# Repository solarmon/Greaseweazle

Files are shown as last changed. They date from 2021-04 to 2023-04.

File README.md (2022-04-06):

# Greaseweazle Projects
Greaseweazle Projects

Various PCB projects based on **keirf**'s Greaseweazle project for reading and writing floppy disks:

https://github.com/keirf/Greaseweazle

Special thanks to **Stefano Cappelli** of https://www.picoelements.com/ for making the time and effort to beta testing these boards. 

# Greaseweazle F1 Plus

## Features

These are the features of the GW F1 Plus boards.

**Standard Features:**
| | F1 Plus Mini Rev 1.1 | F1 Plus  Rev 1.1 | F1 Plus Gotek	 Rev 1.1 | F1 Plus 3.5" Rev 1.1 |
|---|---|---|---|---|
|Jumperless Update|Yes|Yes|Yes|Yes|
|Multiple Drives|Yes|Yes|Yes|Yes|
|Write-Protect Jumper| - |Yes|Yes|Yes|
|Buffered Outputs| - |Yes|Yes|Yes|
|High-Speed USB| - | - | - | - |			
|12v Power| - |Yes|Yes|Yes|
|Flippy Drive| - |Yes|Yes|Yes|
|Disk Change Detect|Yes|Yes|Yes|Yes|
|User Outputs|3|3|3|3|

Note: **Disk Change Detect** allows WinUAE integration - see https://amiga.robsmithdev.co.uk/winuae

The features of the official Greaseweazle models can be seen at:

https://github.com/keirf/Greaseweazle/wiki/Greaseweazle-Models

**Other Features:**
| | F1 Plus Mini Rev 1.1 | F1 Plus  Rev 1.1 | F1 Plus Gotek	 Rev 1.1 | F1 Plus 3.5" Rev 1.1 |
|---|---|---|---|---|
|Gotek Case Form Factor| - | -  |Yes|		-		|
|3.5" Floppy Drive Form Factor| - | - |		-		|			Yes|
|STM32 Blue Pill MCU|Yes|Yes|Yes|Yes|
|**Arduino Nano Track Display:**| - | - |		Yes|				Yes|
|	- LEDC68 Display| - | - |			Yes|				Yes|
|	- 0.91" OLED Display| - | - |		(Yes)|			Yes|
|	- 0.96" OLED Display| - | - |		(Yes)|			Yes|
|	- SD Card Reader| - | - |			Yes|				Yes|
|USB ESD Protection| - | (Yes) |				Yes|				Yes|
|12V Reverse Polarity Protection| - | Yes |	Yes|				Yes|
|Poly Fuse| - |Yes|						Yes|				Yes|
|**LED Status:**|Yes|Yes|						Yes|				Yes|
|	- Activity|Yes|Yes|					Yes|				Yes|
|	- 3.3V|Yes|Yes|						Yes|				Yes|
|	- 5V|Yes|Yes|							Yes|				Yes|
|	- 12V| - |Yes |							Yes|				Yes|
| - Type: SMT|Yes|Yes| - | Yes|
| - Type: THT|Yes|Yes| Yes | Yes|
|**Power Jumpers:**|Yes|Yes|						Yes|				Yes|
|	- 12V|-|Yes|Yes|Yes|
|	- 5V|Yes|Yes|Yes|Yes|
|Write Enable Jumper| - |Yes|				Yes|				Yes|
|Input pullups|Yes|Yes|					Yes|				Yes|
|Reset Button|Yes|Yes|					Yes|				Yes|
|Serial Programming Header|Yes|Yes|		Yes|				Yes|
|SWD Programming Header|-|Yes|			Yes|				Yes|
|Disk Change Jumper|Yes|Yes|Yes|Yes|

**Note:** The **Disk Change Jumper** allows you to use an Amiga drive with WinUAE.

## Greaseweazle F1 Plus Mini Rev 1.1

**Design Files:** https://github.com/solarmon/Greaseweazle/tree/main/Greaseweazle%20F1%20Plus%20Mini%20Rev%201.1

This is the most basic F1 Plus model and has the smallest footprint.

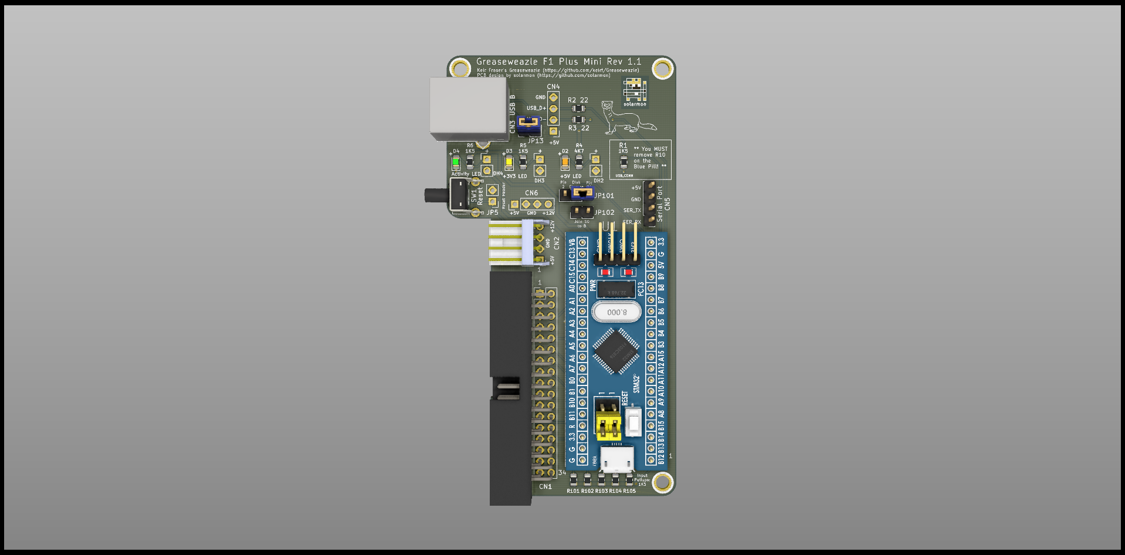
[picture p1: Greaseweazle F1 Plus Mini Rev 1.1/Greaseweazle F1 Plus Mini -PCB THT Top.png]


## Greaseweazle F1 Plus Rev 1.1

**Design Files:** https://github.com/solarmon/Greaseweazle/tree/main/Greaseweazle%20F1%20Plus%20Rev%201.1

This is the standard F1 Plus model, has a standard footprint but no Track Display features. 

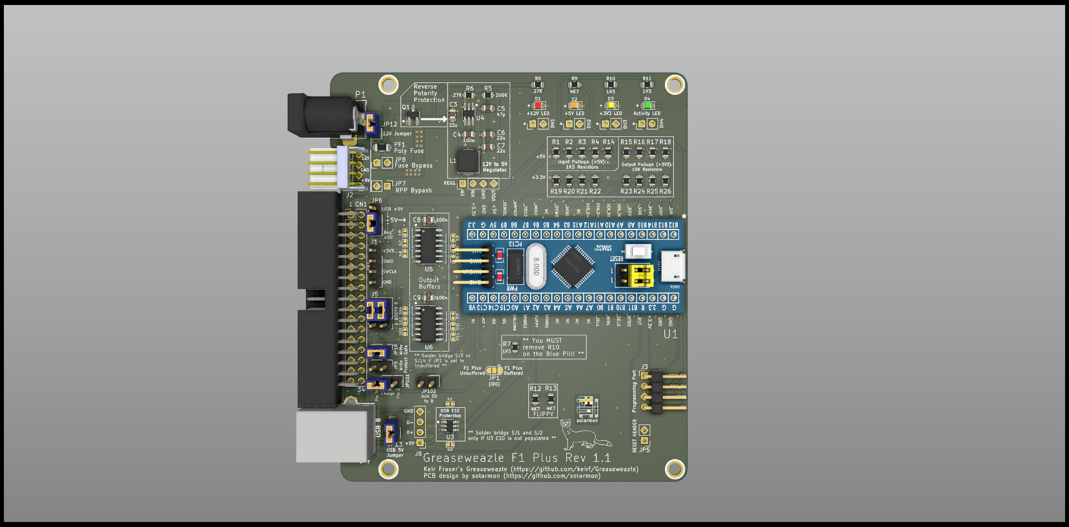
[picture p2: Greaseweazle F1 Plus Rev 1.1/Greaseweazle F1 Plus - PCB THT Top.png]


## Greaseweazle F1 Plus Gotek

**Design Files:** https://github.com/solarmon/Greaseweazle/tree/main/Greaseweazle%20F1%20Plus%20Gotek%20Rev%201.1

This Greaseweazle board has been designed to re-purpose and fit into an original Gotek case; and to make use of its LEDC68 display as a track display.

It has been designed to sit on top of the floppy drive that is connected to it.

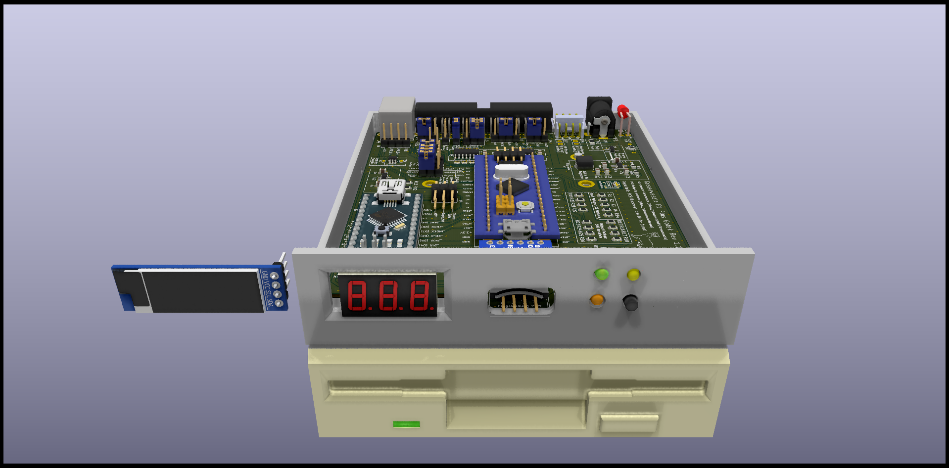
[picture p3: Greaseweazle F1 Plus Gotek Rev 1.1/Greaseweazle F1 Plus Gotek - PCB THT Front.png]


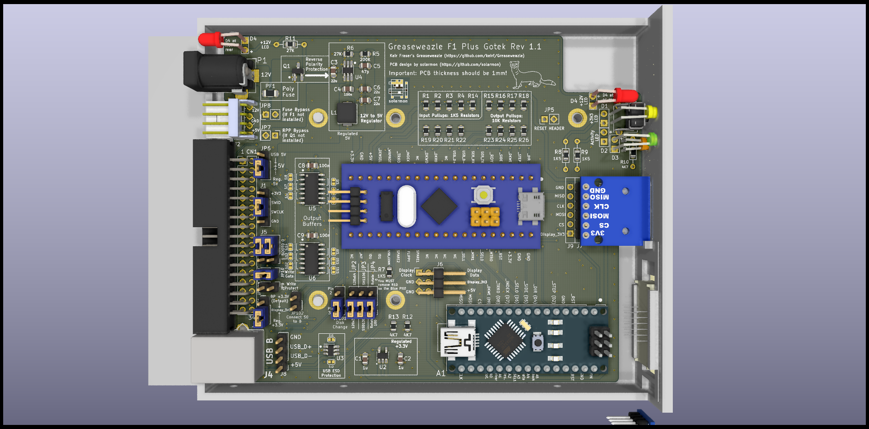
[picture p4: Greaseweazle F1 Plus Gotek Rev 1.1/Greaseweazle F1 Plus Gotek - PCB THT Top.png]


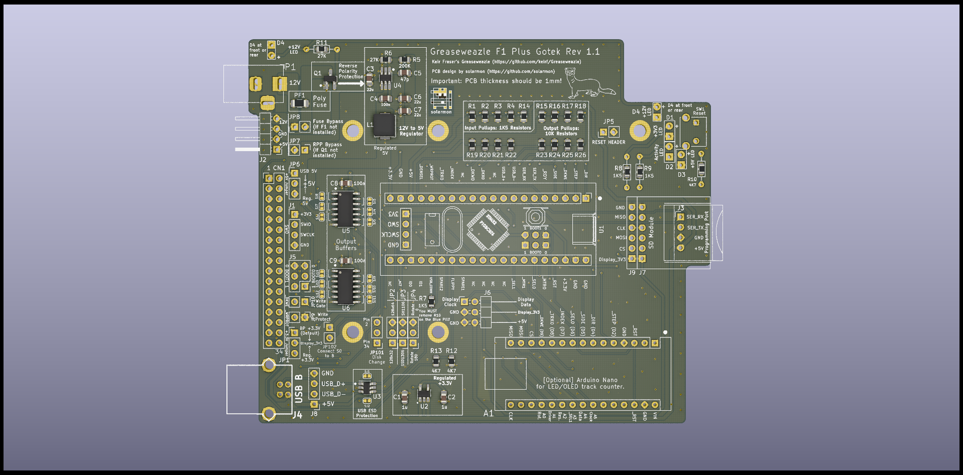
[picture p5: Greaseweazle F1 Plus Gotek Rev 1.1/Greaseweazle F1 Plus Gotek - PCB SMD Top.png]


## Greaseweazle F1 Plus 3.5"

**Design Files:** https://github.com/solarmon/Greaseweazle/tree/main/Greaseweazle%20F1%20Plus%203.5%20Rev%201.1

This Greaseweazle board has been designed to have a 3.5" floppy drive mounted directly on top of it, using the floppy drive standard mounting holes.

The track display feature can support the LEDC68 Gotek LED display, or a 128x32 0.91" OLED display, or a 128x64 0.96" OLED display.

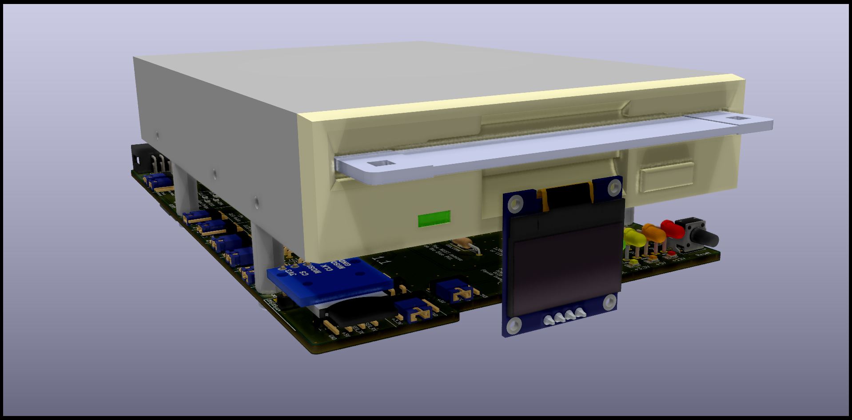
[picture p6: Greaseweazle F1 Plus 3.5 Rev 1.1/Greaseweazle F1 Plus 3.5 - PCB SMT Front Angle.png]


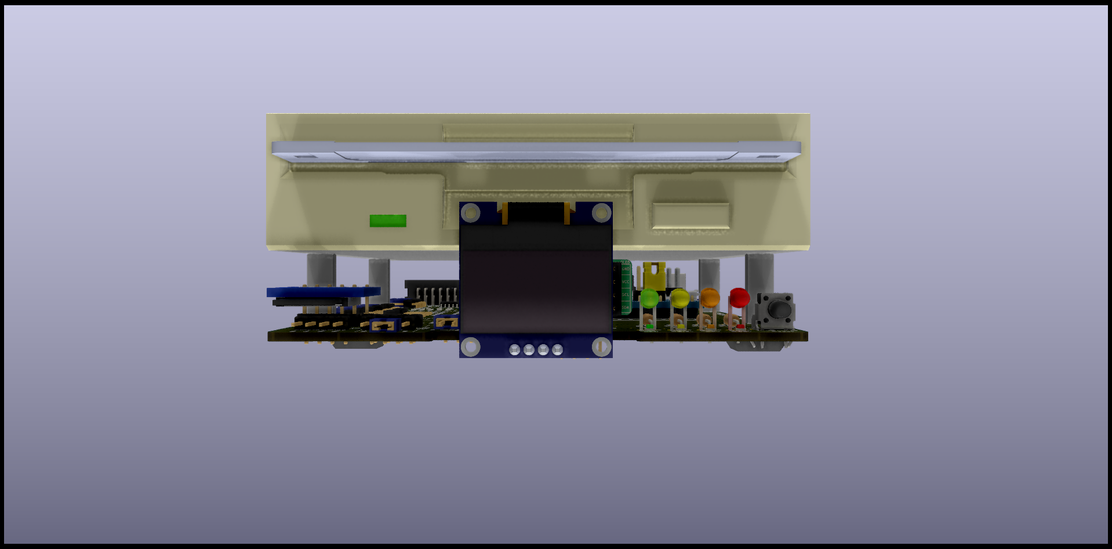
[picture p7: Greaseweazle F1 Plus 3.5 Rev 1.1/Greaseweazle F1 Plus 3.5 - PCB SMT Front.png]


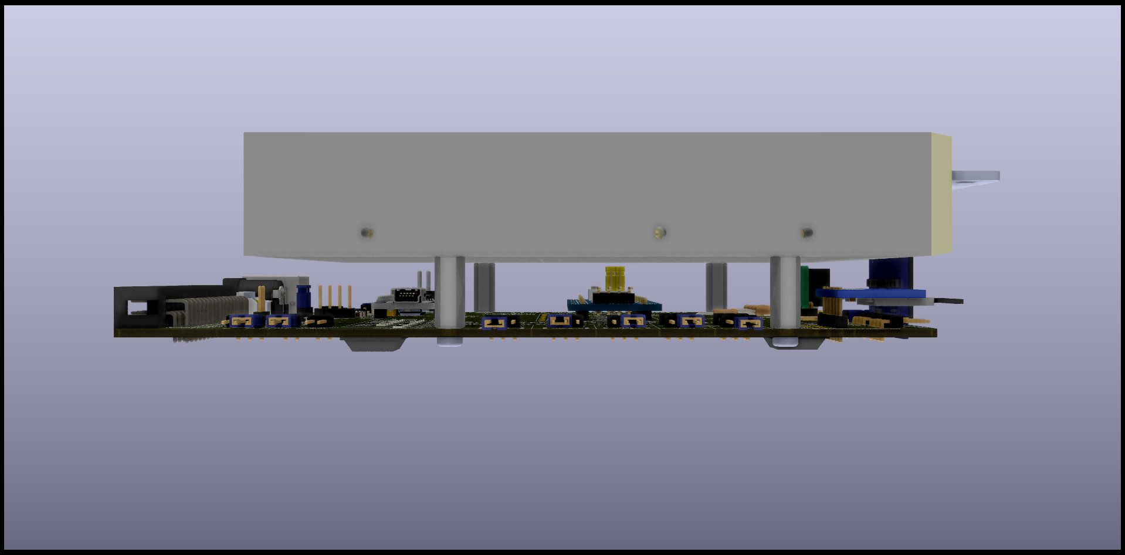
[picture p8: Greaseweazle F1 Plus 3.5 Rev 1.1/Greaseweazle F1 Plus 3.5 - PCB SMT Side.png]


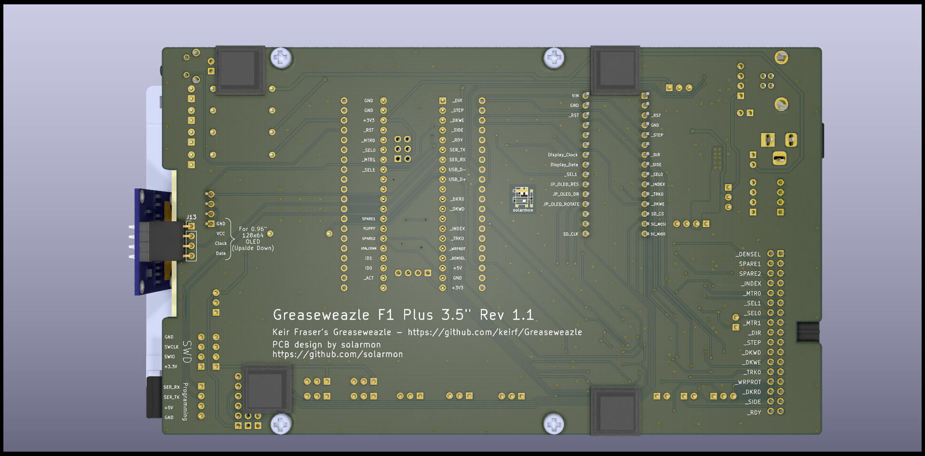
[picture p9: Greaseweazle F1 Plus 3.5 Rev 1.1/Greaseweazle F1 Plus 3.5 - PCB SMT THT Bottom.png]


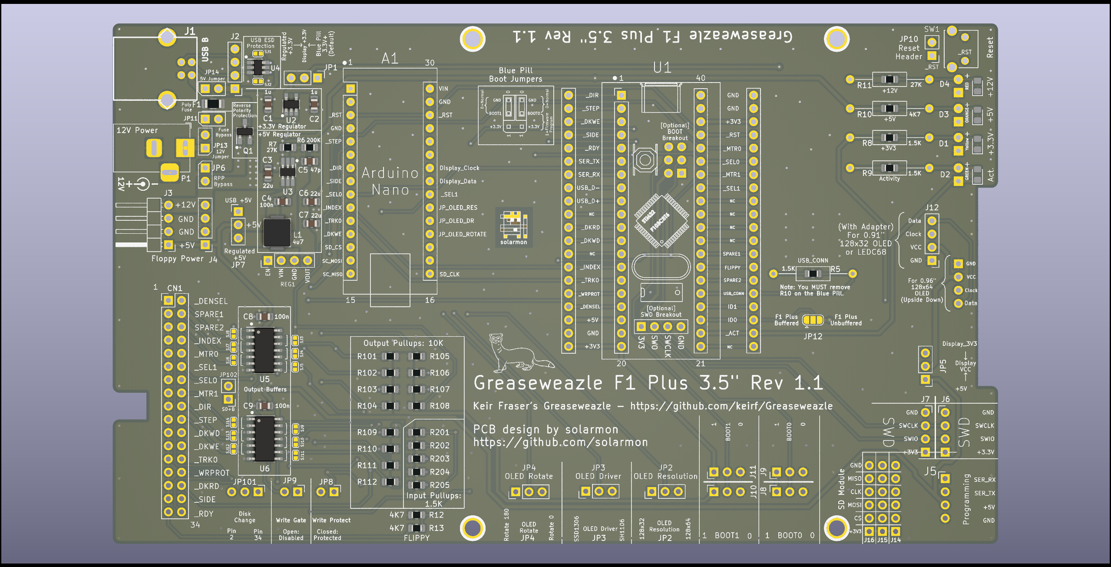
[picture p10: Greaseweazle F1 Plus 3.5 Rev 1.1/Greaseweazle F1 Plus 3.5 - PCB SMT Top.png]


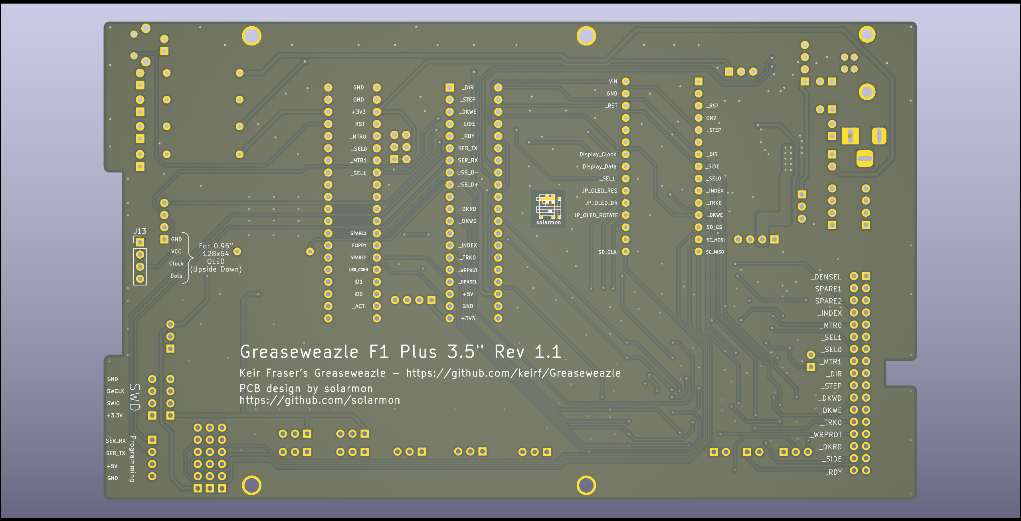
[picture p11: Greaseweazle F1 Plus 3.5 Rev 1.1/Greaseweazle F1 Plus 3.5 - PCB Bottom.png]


## Track Display

The GW F1 Plus Gotek/3.5" Track Display is provided by an Arduino Nano. The Arduino sketch for this can be found at:

https://github.com/solarmon/Greaseweazle/tree/main/Arduino_Nano_GW_F1_Plus_Floppy_Drive_Track_Display_LED_and_OLED

The LEDC68 and OLED display adapter board, used in the GW F1 3.5" and GW F1 Plus 3.5" boards, can be found at:

https://github.com/solarmon/Greaseweazle/tree/main/LEDC68%20and%200.9%20Inch%20OLED%20Adapter

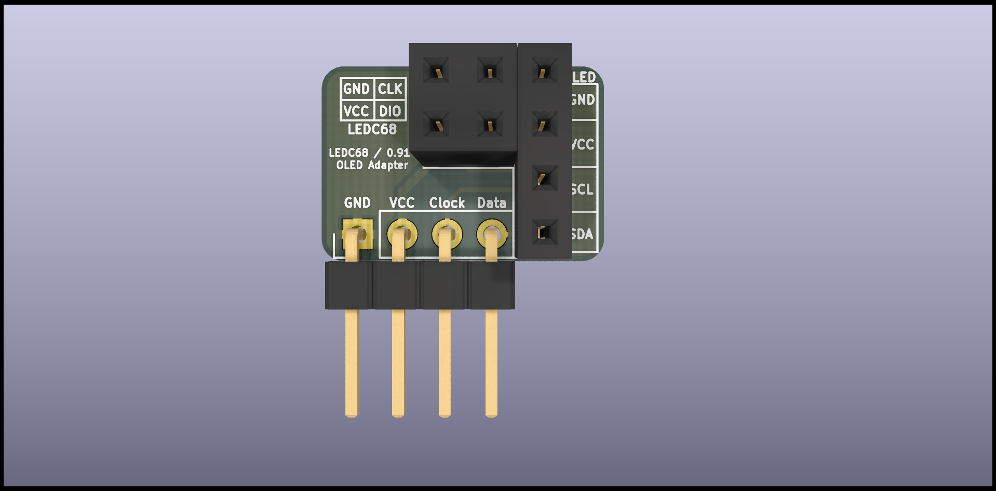
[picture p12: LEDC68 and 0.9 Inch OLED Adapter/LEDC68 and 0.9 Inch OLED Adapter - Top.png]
Top


# Older Revisions

Design files for older revisions of the GW F1 boards can be found at:

## GW F1 Plus Mini

* Rev 1: https://github.com/solarmon/Greaseweazle/tree/main/Greaseweazle%20F1%20Plus%20Mini
 
## GW F1 Plus

* Rev 1: https://github.com/solarmon/Greaseweazle/tree/main/Greaseweazle%20F1%20Plus

## GW F1 Plus Gotek

* Rev 1: https://github.com/solarmon/Greaseweazle/tree/main/Greaseweazle%20F1%20Plus%20Gotek

## GW F1 Plus 3.5"

* Rev 1: https://github.com/solarmon/Greaseweazle/tree/main/Greaseweazle%20F1%20Plus%203.5

## GW F1 Gotek

* Rev 1 (USB-B): https://github.com/solarmon/Greaseweazle/tree/main/Greaseweazle%20F1%20in%20a%20Gotek%20Case%20(%2B%20USB%20B)
* Rev 1 (USB-A): https://github.com/solarmon/Greaseweazle/tree/main/Greaseweazle%20F1%20in%20a%20Gotek%20Case%20(USB-A)
* Rev 2: https://github.com/solarmon/Greaseweazle/tree/main/Greaseweazle%20F1%20Gotek%20Rev%202
* Rev 2B: https://github.com/solarmon/Greaseweazle/tree/main/Greaseweazle%20F1%20Gotek%20Rev%202B

## GW F1 3.5"

* Rev 1: https://github.com/solarmon/Greaseweazle/tree/main/Greaseweazle%20F1%203.5%20Inch
* Rev 2: https://github.com/solarmon/Greaseweazle/tree/main/Greaseweazle%20F1%203.5%20Inch%20Rev%202
* Rev 2B: https://github.com/solarmon/Greaseweazle/tree/main/Greaseweazle%20F1%203.5%20Inch%20Rev%202B

## Track Display

These older revision GW F1 Plus Track Display is provided by an Arduino Nano. The Arduino sketch for this can be found at:

https://github.com/solarmon/Greaseweazle/tree/main/Arduino_Nano_GW_F1_Floppy_Drive_Track_Display_LED_and_OLED_v1

The LEDC68 and OLED display adapter board can be found at:

https://github.com/solarmon/Greaseweazle/tree/main/LEDC68%20and%200.9%20Inch%20OLED%20Adapter

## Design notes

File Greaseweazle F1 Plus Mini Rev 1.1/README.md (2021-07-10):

# Greaseweazle F1 Plus Mini

This is the most basic F1 Plus model and has the smallest footprint.

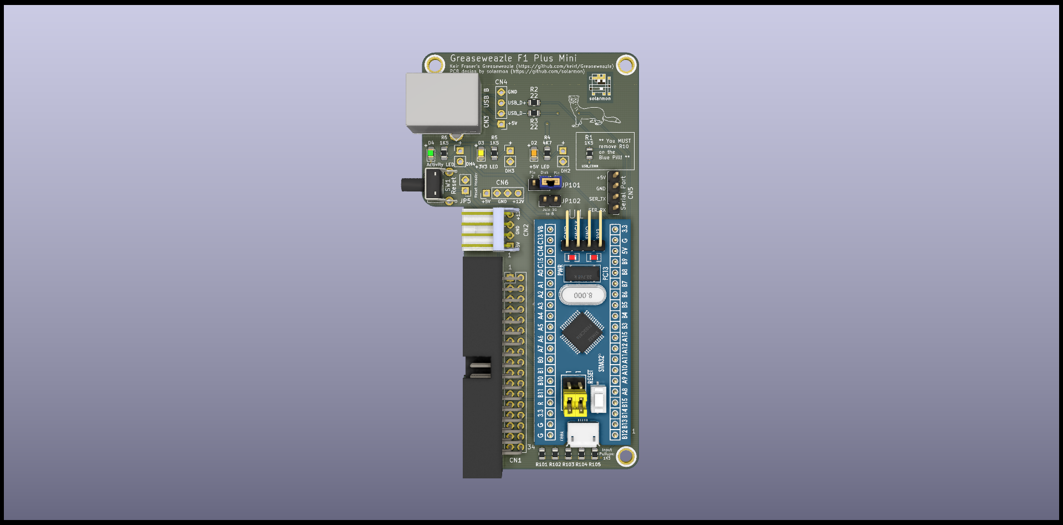
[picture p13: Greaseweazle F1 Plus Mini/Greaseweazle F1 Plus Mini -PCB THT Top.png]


## Jumpers

* **JP101** - Disk Change
  - **Pin 34** (Default) - For PC drives
  - **Pin 2** - For Amiga drives

* **JP102** - Join S0/B
  - If **JP101** set to **Pin 2** then set JP102 to join S0 with B

To use an **Amiga** floppy drive with WinUAE, jumper **JP101** to **Pin 2** and jumper **JP102**. An Amiga drive set to S0 will be usable in WinuAE as drive B.

## Headers

* **JP5** - Reset

* **CN4** - USB Header

* **CN5** - Serial Port

* **DH2** - +5V LED
* **DH3** - +3V3 LED
* **DH4** - ACT LED

## Connectors

* **CN1** - Floppy Data
* **CN2** - Floppy Power (Out)
* **CN3** - USB B
* **CN6** - Floppy Power (In)

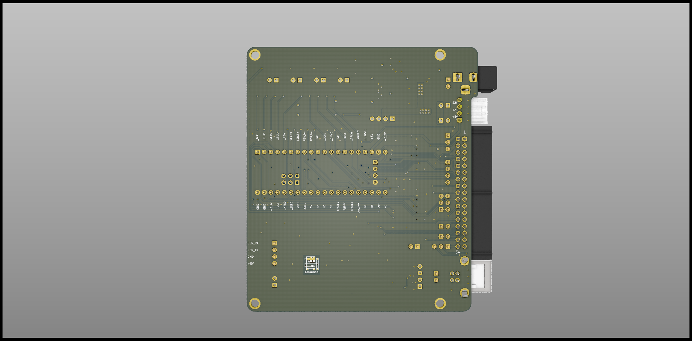
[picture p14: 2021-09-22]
Greaseweazle F1 Plus Rev 1.1/Greaseweazle F1 Plus - PCB THT Bottom.png

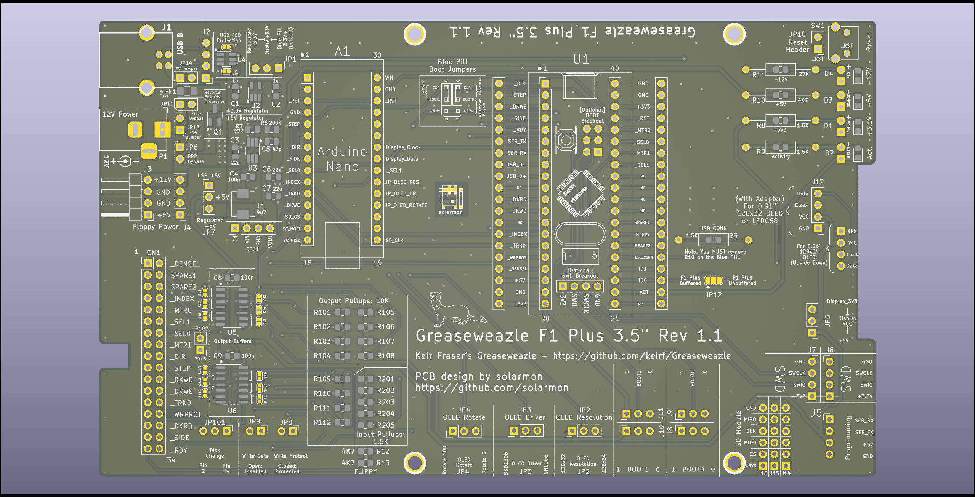
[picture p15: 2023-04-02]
Greaseweazle F1 Plus 3.5 Rev 1.1/Greaseweazle F1 Plus 3.5 - PCB Top.png

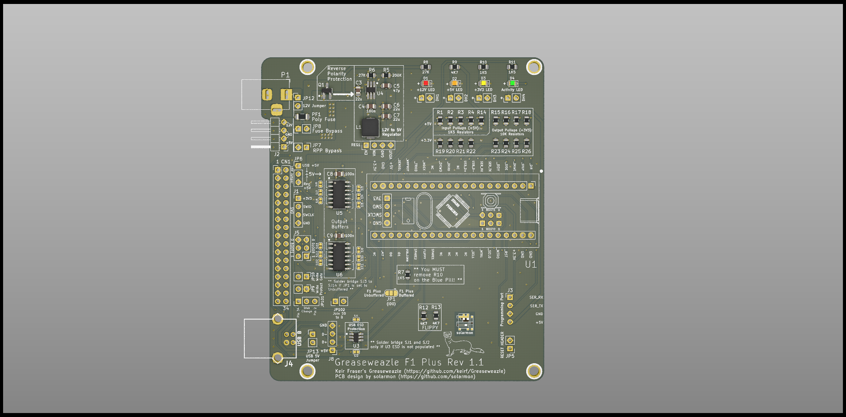
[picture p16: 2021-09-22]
Greaseweazle F1 Plus Rev 1.1/Greaseweazle F1 Plus - PCB SMT Top.png

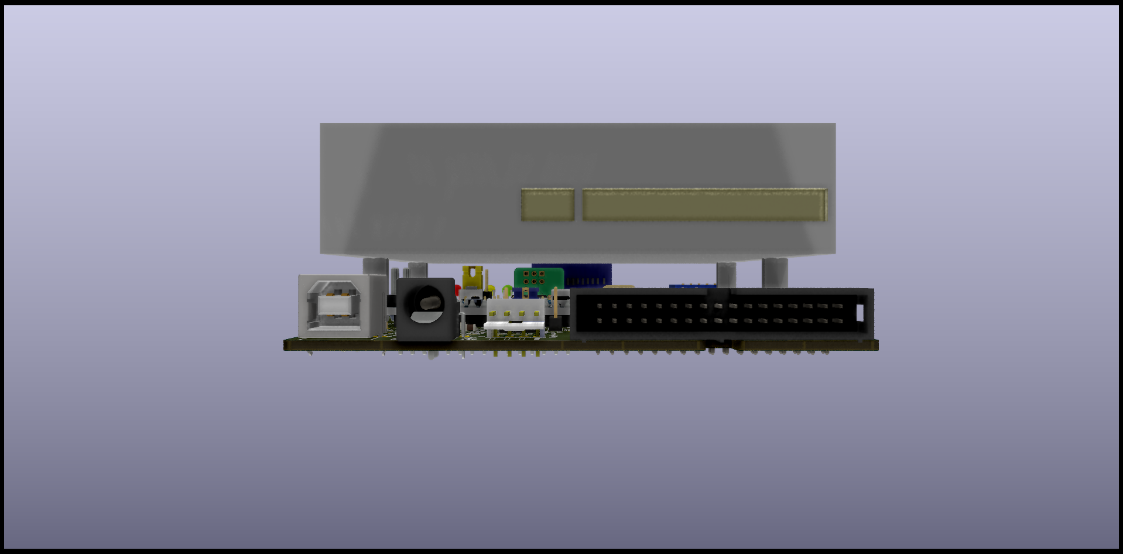
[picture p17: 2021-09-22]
Greaseweazle F1 Plus 3.5 Rev 1.1/Greaseweazle F1 Plus 3.5 - PCB SMT Rear.png

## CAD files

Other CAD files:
LEDC68 and 0.9 Inch OLED Adapter/DXF/LEDC68 and 0.9 Inch OLED Adapter-B_SilkS.dxf
LEDC68 and 0.9 Inch OLED Adapter/DXF/LEDC68 and 0.9 Inch OLED Adapter-F_SilkS.dxf

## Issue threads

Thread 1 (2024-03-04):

3D model of the FDD connector

Freiwind, 2024-03-04:
The first pin on the 3D model of the FDD connector does not match specified on the PCB.
It must be turned 180 degrees.

solarmon, 2024-03-04:
Hi,

For which Greaseweazle model?

Regards.

Freiwind, 2024-03-04:
At least for F1 Plus Gotek Rev 1.1 and F1 Plus Rev 1.1
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

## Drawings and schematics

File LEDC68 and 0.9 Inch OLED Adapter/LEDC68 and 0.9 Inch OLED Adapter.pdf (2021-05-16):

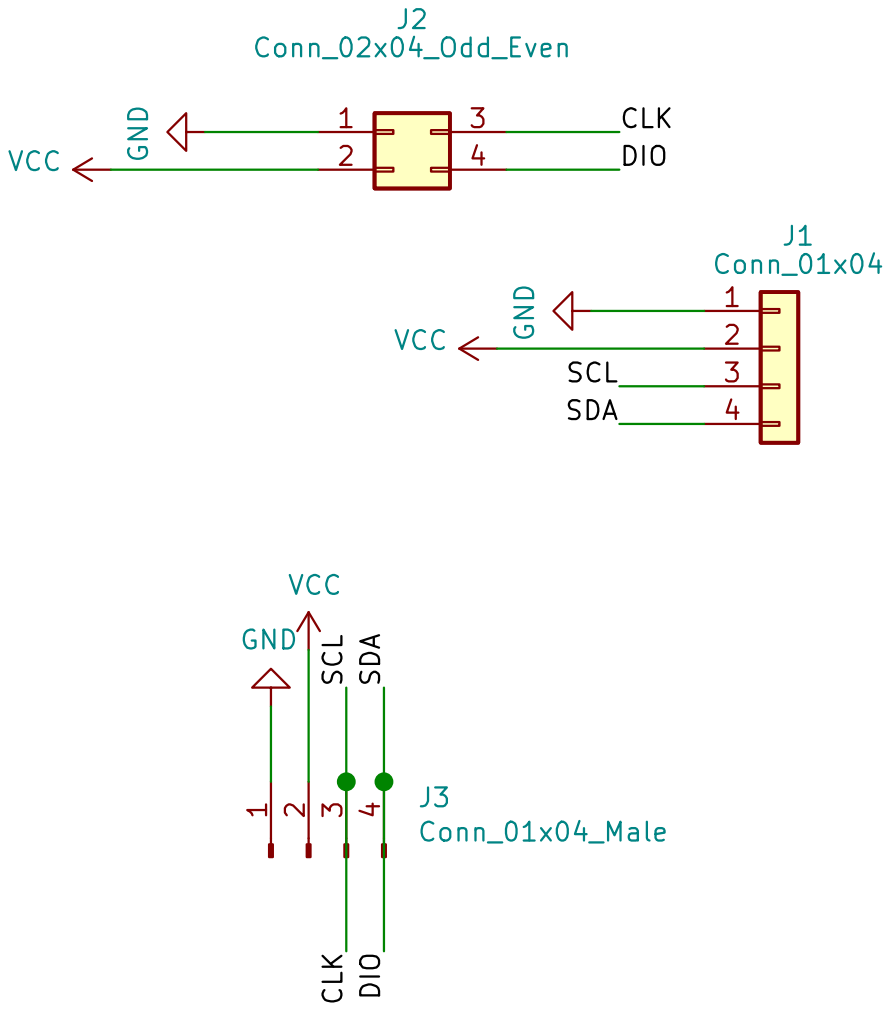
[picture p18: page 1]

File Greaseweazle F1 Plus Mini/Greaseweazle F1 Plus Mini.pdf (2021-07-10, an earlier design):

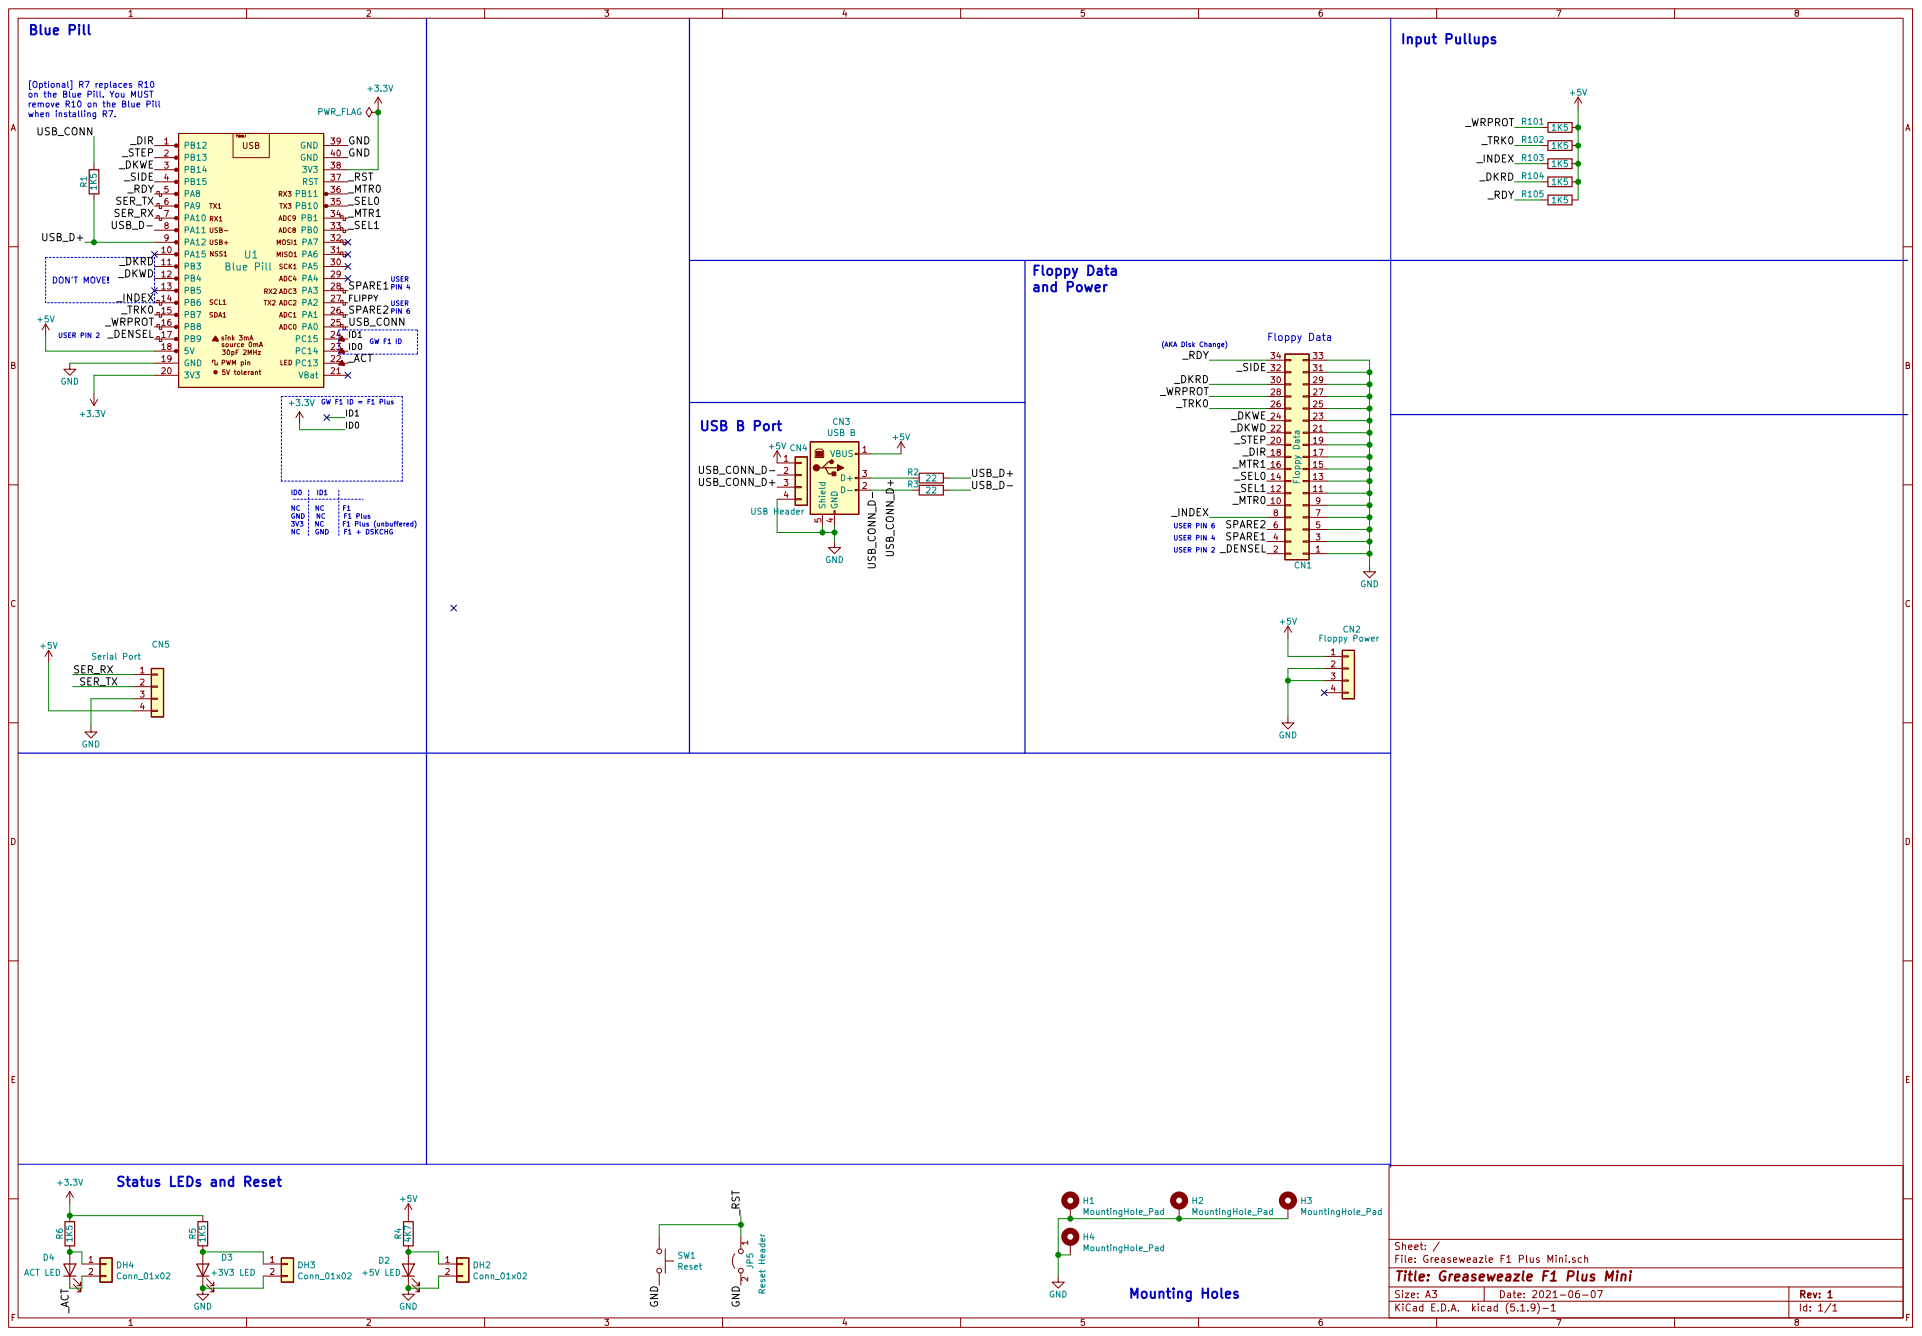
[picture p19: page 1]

[Optional] R7 replaces R10
on the Blue Pill. You MUST

5 CN3 USB B GND R6 1K5 D4 ACT LED

Status LEDs and Reset

Id: 1/1 Title: Greaseweazle F1 Plus Mini File: Greaseweazle F1 Plus Mini.sch Sheet: / R5 1K5

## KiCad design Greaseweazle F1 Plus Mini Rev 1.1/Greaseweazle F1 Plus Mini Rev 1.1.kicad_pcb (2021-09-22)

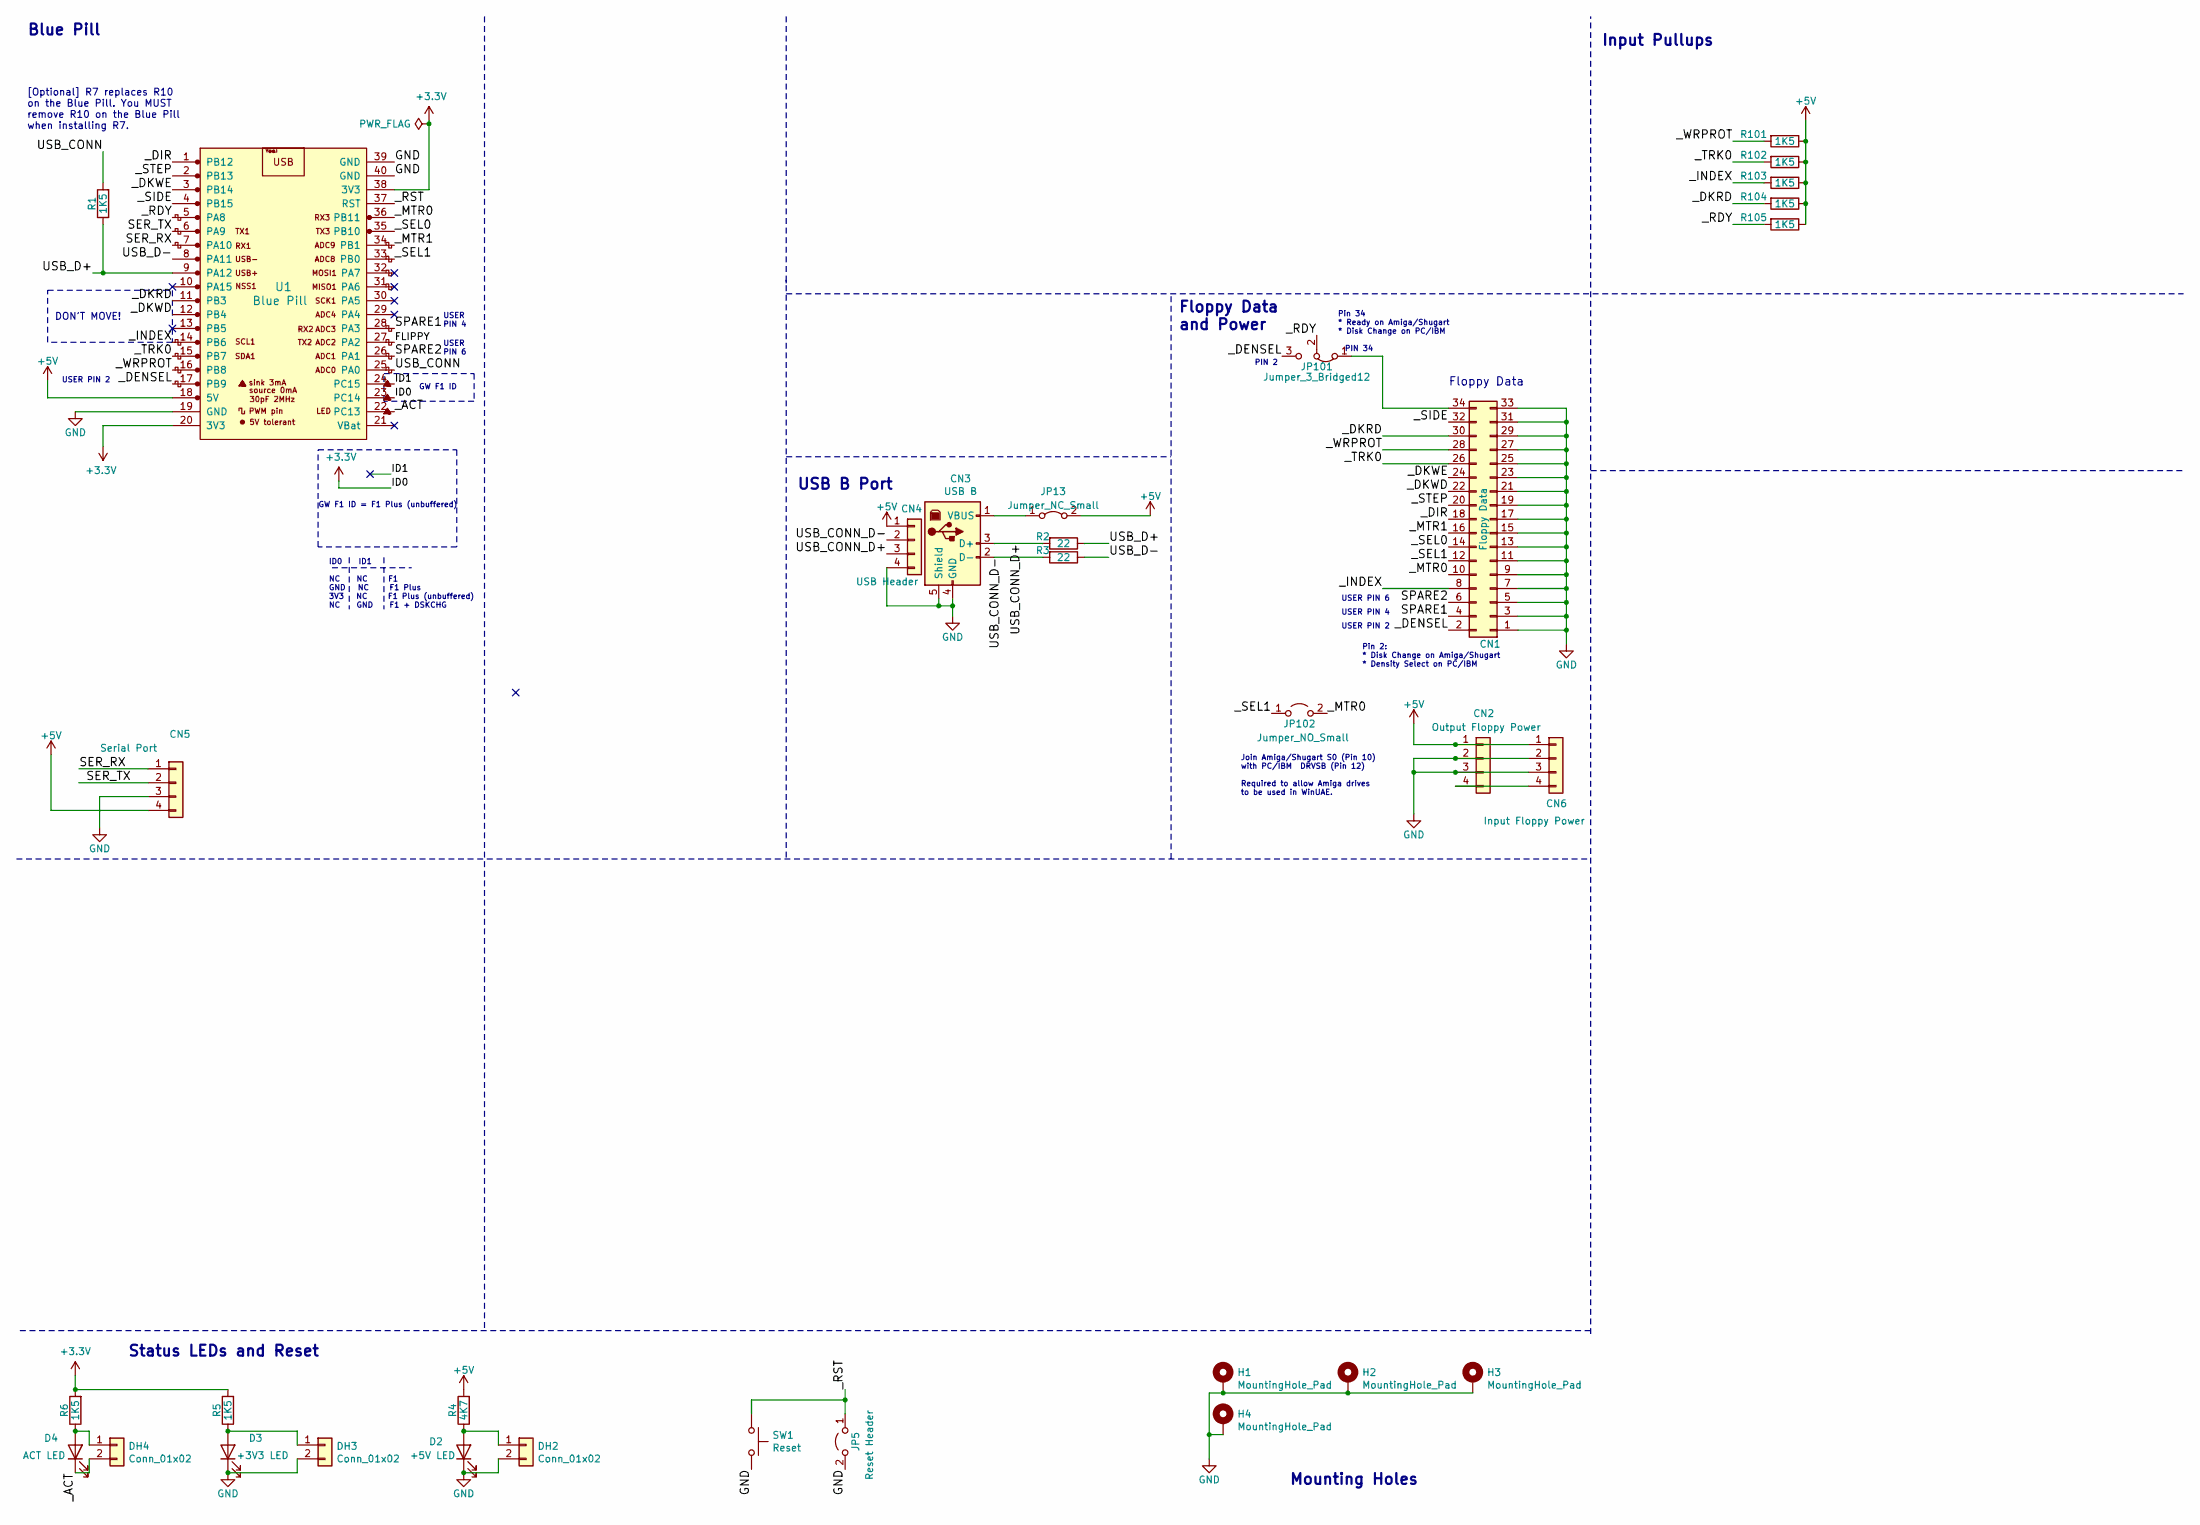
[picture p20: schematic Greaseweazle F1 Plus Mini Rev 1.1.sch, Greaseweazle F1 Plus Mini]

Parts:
CN1: Floppy Data; PinHeader_2x17_P2.54mm_Vertical
CN2: Output Floppy Power; PinHeader_1x04_P2.54mm_Horizontal
CN3: USB B; conn_usb_B; LCSC C498173
CN4: USB Header; PinHeader_1x04_P2.54mm_Vertical
CN5: Serial Port; PinHeader_1x04_P2.54mm_Vertical
CN6: Input Floppy Power; PinHeader_1x04_P2.54mm_Vertical
D2: +5V LED; LED_0805_2012Metric_Pad1.15x1.40mm_HandSolder
D3: +3V3 LED; LED_0805_2012Metric_Pad1.15x1.40mm_HandSolder
D4: ACT LED; LED_0805_2012Metric_Pad1.15x1.40mm_HandSolder
DH2, DH3, DH4: Conn_01x02; PinHeader_1x02_P2.54mm_Vertical
H1, H2, H3, H4: MountingHole_Pad; HOLE_3MM
JP5: Reset Header; PinHeader_1x02_P2.54mm_Vertical
JP13: Jumper_NC_Small; PinHeader_1x02_P2.54mm_Vertical
JP101: Jumper_3_Bridged12; PinHeader_1x03_P2.54mm_Vertical
JP102: Jumper_NO_Small; PinHeader_1x02_P2.54mm_Vertical
R1, R101, R102, R103, R104, R105: 1K5; R_0805_2012Metric
R2, R3: 22; R_0805_2012Metric
R4: 4K7; R_0805_2012Metric_Pad1.20x1.40mm_HandSolder
R5, R6: 1K5; R_0805_2012Metric_Pad1.20x1.40mm_HandSolder
SW1: Reset; SW_Tactile_SPST_Angled_PTS645Vx83-2LFS
U1: Blue Pill; YAAJ_BluePill_1

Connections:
+3V3: R5.2, R6.2, U1.20 (3V3), U1.23 (PC14), U1.38 (3V3)
+5V: CN2.1, CN4.1, CN5.4, CN6.1, JP13.2 (B), R4.2, R101.1, R102.1, R103.1, R104.1, R105.1, U1.18 (5V)
/FLIPPY: U1.27 (PA2)
/ID1: U1.24 (PC15)
/SER_RX: CN5.1, U1.7 (PA10)
/SER_TX: CN5.2, U1.6 (PA9)
/SPARE1: CN1.4, U1.28 (PA3)
/SPARE2: CN1.6, U1.26 (PA1)
/USB_CONN: R1.2, U1.25 (PA0)
/USB_CONN_D+: CN3.3 (D+), CN4.3, R2.2
/USB_CONN_D-: CN3.2 (D-), CN4.2, R3.2
/USB_D+: R1.1, R2.1, U1.9 (PA12)
/USB_D-: R3.1, U1.8 (PA11)
/_ACT: D4.1 (K), DH4.2, U1.22 (PC13)
/_DENSEL: CN1.2, JP101.3 (B), U1.17 (PB9)
/_DIR: CN1.18, U1.1 (PB12)
/_DKRD: CN1.30, R104.2, U1.11 (PB3)
/_DKWD: CN1.22, U1.12 (PB4)
/_DKWE: CN1.24, U1.3 (PB14)
/_INDEX: CN1.8, R103.2, U1.14 (PB6)
/_MTR0: CN1.10, JP102.2 (B), U1.36 (PB11)
/_MTR1: CN1.16, U1.34 (PB1)
/_RDY: JP101.2 (C), R105.2, U1.5 (PA8)
/_RST: JP5.1 (A), SW1.1, U1.37 (RST)
/_SEL0: CN1.14, U1.35 (PB10)
/_SEL1: CN1.12, JP102.1 (A), U1.33 (PB0)
/_SIDE: CN1.32, U1.4 (PB15)
/_STEP: CN1.20, U1.2 (PB13)
/_TRK0: CN1.26, R102.2, U1.15 (PB7)
/_WRPROT: CN1.28, R101.2, U1.16 (PB8)
GND: CN1.1, CN1.3, CN1.5, CN1.7, CN1.9, CN1.11, CN1.13, CN1.15, CN1.17, CN1.19, CN1.21, CN1.23, CN1.25, CN1.27, CN1.29, CN1.31, CN1.33, CN2.2, CN2.3, CN3.4 (GND), CN3.5 (Shield), CN4.4, CN5.3, CN6.2, CN6.3, D2.1 (K), D3.1 (K), DH2.2, DH3.2, H1.1, H2.1, H3.1, H4.1, JP5.2 (B), SW1.2, U1.19 (GND), U1.39 (GND), U1.40 (GND)
unnamed: CN1.34, JP101.1 (A)
unnamed: CN2.4, CN6.4
unnamed: CN3.1 (VBUS), JP13.1 (A)
unnamed: D2.2 (A), DH2.1, R4.1
unnamed: D3.2 (A), DH3.1, R5.1
unnamed: D4.2 (A), DH4.1, R6.1

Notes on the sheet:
Floppy Data
[Optional] R7 replaces R10 on the Blue Pill. You MUST remove R10 on the Blue Pill when installing R7.
USB B Port
Floppy Data and Power
Blue Pill
Status LEDs and Reset
Mounting Holes
GW F1 ID = F1 Plus (unbuffered)
GW F1 ID
DON'T MOVE!
Input Pullups
USER PIN 2
USER PIN 4
USER PIN 6
USER PIN 4
USER PIN 6
Pin 34 * Ready on Amiga/Shugart * Disk Change on PC/IBM
ID0 ID1 NC NC F1 GND NC F1 Plus 3V3 NC F1 Plus (unbuffered) NC GND F1 + DSKCHG
Pin 2: * Disk Change on Amiga/Shugart * Density Select on PC/IBM
Join Amiga/Shugart S0 (Pin 10) with PC/IBM DRVSB (Pin 12) Required to allow Amiga drives to be used in WinUAE.
PIN 2
PIN 34

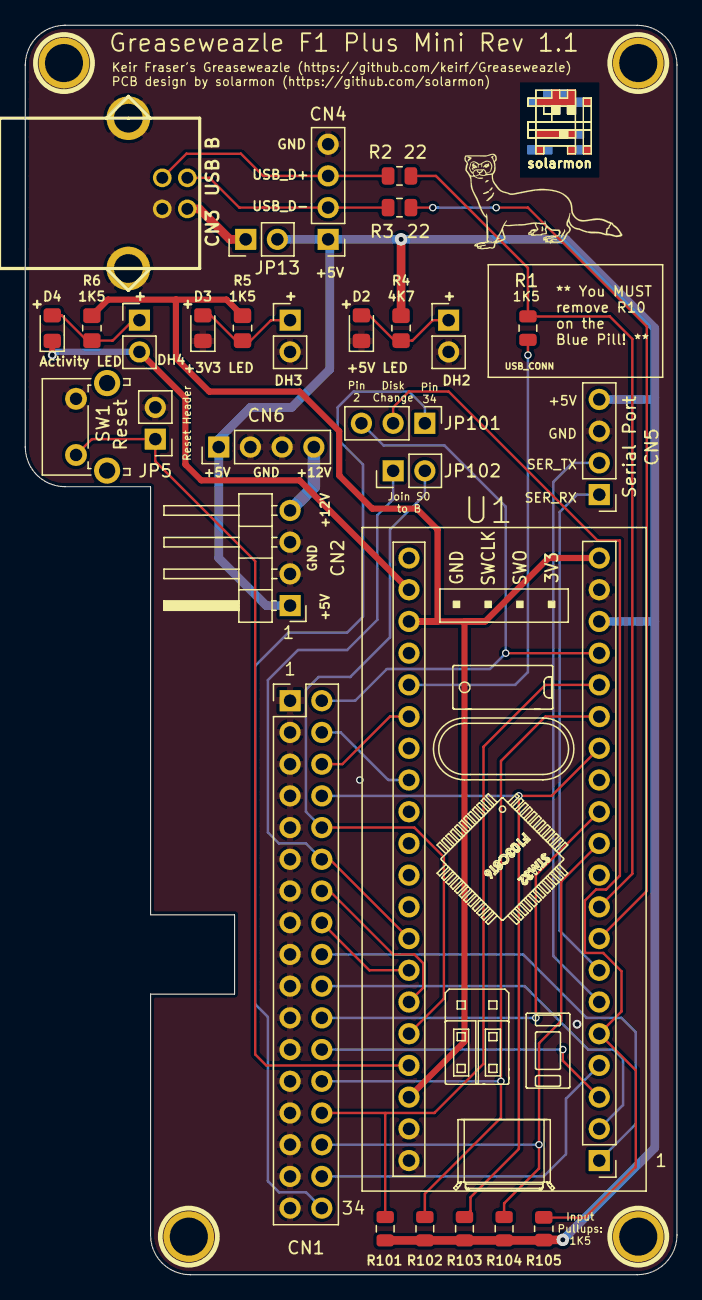
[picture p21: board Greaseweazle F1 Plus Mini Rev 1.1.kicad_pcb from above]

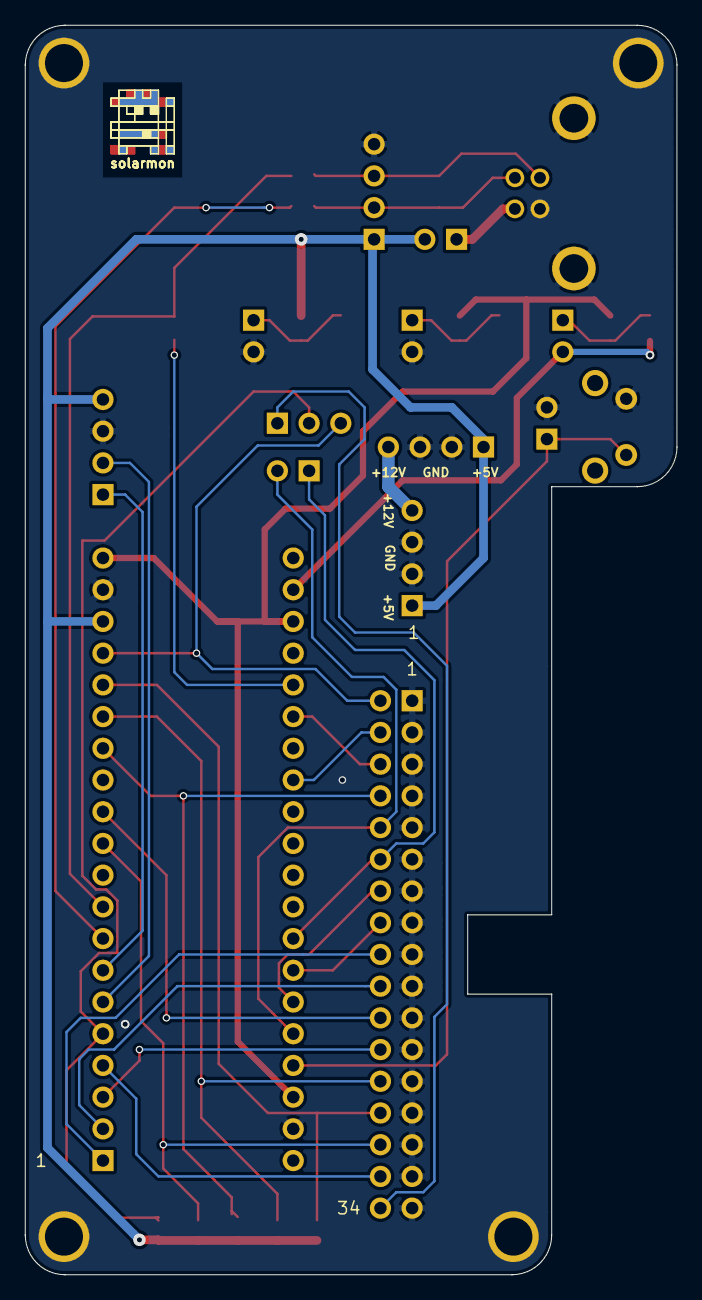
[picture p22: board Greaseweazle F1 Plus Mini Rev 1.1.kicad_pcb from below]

Board: 2 copper layers, 52.2 x 100.1 mm, 38 parts (2 on the bottom side), 35 nets.

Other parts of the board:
G**: Weasle; WeasleLogo
solarmon: solarmon-logo-25mils
solarmon#2, solarmon#3, solarmon#4: solarmon-logo-25mils

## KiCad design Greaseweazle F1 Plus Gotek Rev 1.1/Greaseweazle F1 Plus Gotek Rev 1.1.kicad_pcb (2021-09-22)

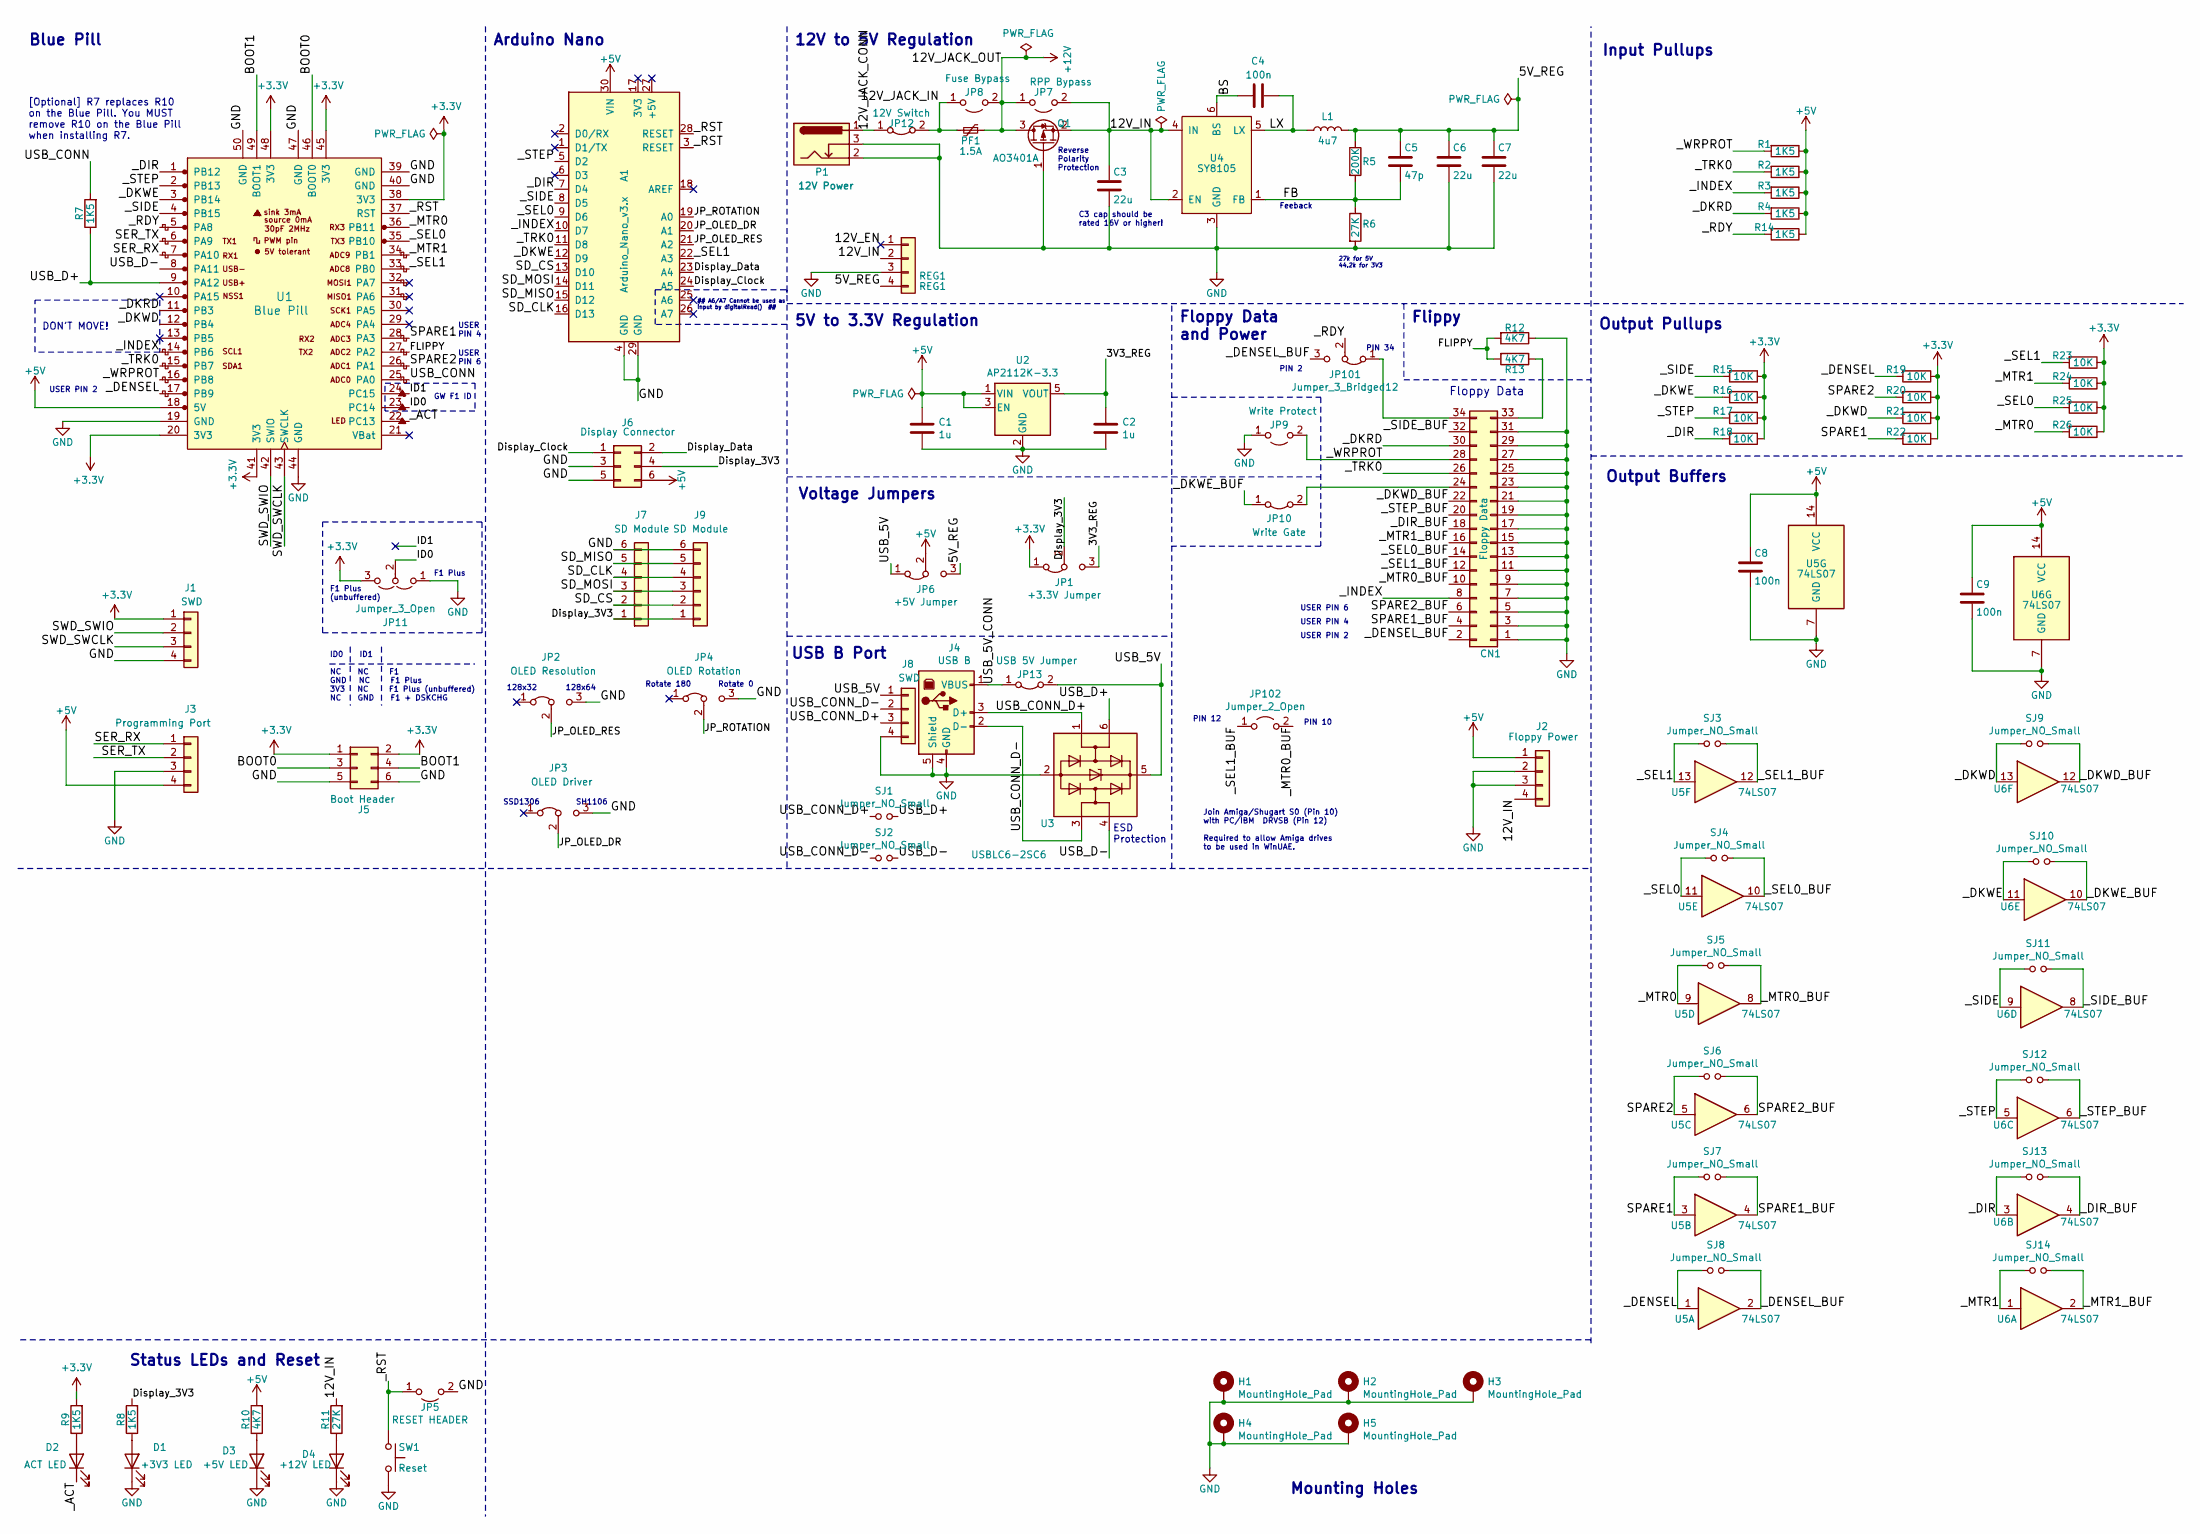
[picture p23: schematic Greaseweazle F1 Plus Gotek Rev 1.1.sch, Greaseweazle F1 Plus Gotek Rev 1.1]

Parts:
A1: Arduino_Nano_v3.x; Arduino_Nano
C1, C2: 1u; C_0805_2012Metric_Pad1.15x1.40mm_HandSolder
C3, C6, C7: 22u; C_0805_2012Metric_Pad1.15x1.40mm_HandSolder
C4, C8, C9: 100n; C_0805_2012Metric_Pad1.15x1.40mm_HandSolder
C5: 47p; C_0805_2012Metric_Pad1.15x1.40mm_HandSolder
CN1: Floppy Data; PinHeader_2x17_P2.54mm_Vertical
D1: +3V3 LED; LED_D3.0mm_Horizontal_O6.35mm_Z10.0mm
D2: ACT LED; LED_D3.0mm_Horizontal_O6.35mm_Z10.0mm
D3: +5V LED; LED_D3.0mm_Horizontal_O3.81mm_Z6.0mm
D4: +12V LED; LED_D3.0mm_Horizontal_O3.81mm_Z6.0mm
H1, H2, H3, H4, H5: MountingHole_Pad; MountingHole_M3_Pad
J1, J8: SWD; PinHeader_1x04_P2.54mm_Vertical
J2: Floppy Power; PinHeader_1x04_P2.54mm_Horizontal
J3: Programming Port; PinHeader_1x04_P2.54mm_Horizontal
J4: USB B; conn_usb_B; LCSC C498173
J5: Boot Header; PinHeader_2x03_P2.54mm_Vertical
J6: Display Connector; PinHeader_2x03_P2.54mm_Horizontal
J7, J9: SD Module; SD_Micro_Module_Upside_Down
JP1: +3.3V Jumper; PinHeader_1x03_P2.54mm_Vertical
JP2: OLED Resolution; PinHeader_1x03_P2.54mm_Vertical
JP3: OLED Driver; PinHeader_1x03_P2.54mm_Vertical
JP4: OLED Rotation; PinHeader_1x03_P2.54mm_Vertical
JP5: RESET HEADER; PinHeader_1x02_P2.54mm_Vertical
JP6: +5V Jumper; PinHeader_1x03_P2.54mm_Vertical
JP7: RPP Bypass; PinHeader_1x02_P2.54mm_Vertical
JP8: Fuse Bypass; PinHeader_1x02_P2.54mm_Vertical
JP9: Write Protect; PinHeader_1x02_P2.54mm_Vertical
JP10: Write Gate; PinHeader_1x02_P2.54mm_Vertical
JP11: Jumper_3_Open; SolderJumper-3_P1.3mm_Open_RoundedPad1.0x1.5mm
JP12: 12V Switch; PinHeader_1x02_P2.54mm_Vertical
JP13: USB 5V Jumper; PinHeader_1x02_P2.54mm_Vertical
JP101: Jumper_3_Bridged12; PinHeader_1x03_P2.54mm_Vertical
JP102: Jumper_2_Open; PinHeader_1x02_P2.54mm_Vertical
L1: 4u7; MWSA0503S; LCSC C408410
P1: 12V Power; BarrelJack_Horizontal; LCSC C16214
PF1: 1.5A; Fuse_1206_3216Metric_Pad1.42x1.75mm_HandSolder; LCSC C371166
Q1: AO3401A; SOT-23_Handsoldering; LCSC C15127
R1, R2, R3, R4, R7, R8, R9, R14: 1K5; R_0805_2012Metric
R5: 200K; R_0805_2012Metric
R6, R11: 27K; R_0805_2012Metric
R10, R12, R13: 4K7; R_0805_2012Metric
R15, R16, R17, R18, R19, R20, R21, R22, R23, R24, R25, R26: 10K; R_0805_2012Metric
REG1: REG1; PinHeader_1x04_P2.54mm_Vertical
SJ1, SJ2, SJ3, SJ4, SJ5, SJ6, SJ7, SJ8, SJ9, SJ10, SJ11, SJ12, SJ13, SJ14: Jumper_NO_Small; SolderJumper-2_Open_RoundedPad0.5x1.0mm
SW1: Reset; PUSH_BUTTON_RIGHT_ANGLE
U1: Blue Pill; YAAJ_BluePill_SWD_1_BootPins
U2: AP2112K-3.3; SOT-23-5_HandSoldering; LCSC C51118
U3: USBLC6-2SC6; SOT-23-6_Handsoldering; LCSC C7519
U4: SY8105; TSOT-23-6_HandSoldering; LCSC C178247
U5, U6: 74LS07; SOIC-14_3.9x8.7mm_P1.27mm; LCSC C513513

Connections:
+3V3: J1.1, J5.1, J5.2, JP1.1 (A), JP11.3 (B), R9.2, R15.1, R16.1, R17.1, R18.1, R19.1, R20.1, R21.1, R22.1, R23.1, R24.1, R25.1, R26.1, U1.20 (3V3), U1.38 (3V3), U1.41 (3V3), U1.45 (3V3), U1.48 (3V3); also elsewhere on the board
+5V: A1.30 (VIN), C1.1, C8.1, C9.1, J2.1, J3.4, J6.6, JP6.2 (C), R1.1, R2.1, R3.1, R4.1, R10.2, R14.1, U1.18 (5V), U2.1 (VIN), U2.3 (EN), U5.14 (VCC), U6.14 (VCC); also elsewhere on the board
+12V: JP7.1 (A), JP8.2 (B), PF1.1, Q1.3 (D)
/3V3_REG: C2.1, JP1.3 (B), U2.5 (VOUT)
/5V_REG: C5.1, C6.1, C7.1, JP6.3 (B), L1.2, R5.1, REG1.4
/12V_EN: REG1.1
/12V_JACK_CONN: JP12.1 (A), P1.1
/12V_JACK_IN: JP8.1 (A), JP12.2 (B), PF1.2
/BOOT0: J5.3, U1.46 (BOOT0)
/BOOT1: J5.4, U1.49 (BOOT1)
/BS: C4.1, U4.6 (BS)
/Display_3V3: J6.4, J7.1, J9.1, JP1.2 (C), R8.2; also elsewhere on the board
/Display_Clock: A1.24 (A5), J6.1
/Display_Data: A1.23 (A4), J6.2
/FB: C5.2, R5.2, R6.1, U4.1 (FB)
/FLIPPY: R12.2, R13.2, U1.27 (PA2)
/ID0: JP11.2 (C), U1.23 (PC14)
/ID1: U1.24 (PC15)
/JP_OLED_DR: A1.20 (A1), JP3.2 (C)
/JP_OLED_RES: A1.21 (A2), JP2.2 (C)
/JP_ROTATION: A1.19 (A0), JP4.2 (C)
/LX: C4.2, L1.1, U4.5 (LX)
/SD_CLK: A1.16 (D13), J7.4, J9.4
/SD_CS: A1.13 (D10), J7.2, J9.2
/SD_MISO: A1.15 (D12), J7.5, J9.5
/SD_MOSI: A1.14 (D11), J7.3, J9.3
/SER_RX: J3.1, U1.7 (PA10)
/SER_TX: J3.2, U1.6 (PA9)
/SPARE1: R22.2, SJ7.1, U1.28 (PA3), U5.3
/SPARE1_BUF: CN1.4, SJ7.2, U5.4
/SPARE2: R20.2, SJ6.1, U1.26 (PA1), U5.5
/SPARE2_BUF: CN1.6, SJ6.2, U5.6
/SWD_SWCLK: J1.3, U1.43 (SWCLK)
/SWD_SWIO: J1.2, U1.42 (SWIO)
/USB_5V: J8.1, JP6.1 (A), JP13.2 (B), U3.5 (VBUS)
/USB_5V_CONN: J4.1 (VBUS), JP13.1 (A)
/USB_CONN: R7.2, U1.25 (PA0)
/USB_CONN_D+: J4.3 (D+), J8.3, SJ1.1, U3.1 (I/O1)
/USB_CONN_D-: J4.2 (D-), J8.2, SJ2.1, U3.3 (I/O2)
/USB_D+: R7.1, SJ1.2, U1.9 (PA12), U3.6 (I/O1)
/USB_D-: SJ2.2, U1.8 (PA11), U3.4 (I/O2)
/_ACT: D2.1 (K), U1.22 (PC13)
/_DENSEL: R19.2, SJ8.1, U1.17 (PB9), U5.1
/_DENSEL_BUF: CN1.2, JP101.3 (B), SJ8.2, U5.2
/_DIR: A1.7 (D4), R18.2, SJ13.1, U1.1 (PB12), U6.3
/_DIR_BUF: CN1.18, SJ13.2, U6.4
/_DKRD: CN1.30, R4.2, U1.11 (PB3)
/_DKWD: R21.2, SJ9.1, U1.12 (PB4), U6.13
/_DKWD_BUF: CN1.22, SJ9.2, U6.12
/_DKWE: A1.12 (D9), R16.2, SJ10.1, U1.3 (PB14), U6.11
/_DKWE_BUF: JP10.1 (A), SJ10.2, U6.10
/_INDEX: A1.10 (D7), CN1.8, R3.2, U1.14 (PB6)
/_MTR0: R26.2, SJ5.1, U1.36 (PB11), U5.9
/_MTR0_BUF: CN1.10, JP102.2 (B), SJ5.2, U5.8
/_MTR1: R24.2, SJ14.1, U1.34 (PB1), U6.1
/_MTR1_BUF: CN1.16, SJ14.2, U6.2
/_RDY: JP101.2 (C), R14.2, U1.5 (PA8)
/_RST: A1.3 (RESET), A1.28 (RESET), JP5.1 (A), SW1.1, U1.37 (RST)
/_SEL0: A1.9 (D6), R25.2, SJ4.1, U1.35 (PB10), U5.11
/_SEL0_BUF: CN1.14, SJ4.2, U5.10
/_SEL1: A1.22 (A3), R23.2, SJ3.1, U1.33 (PB0), U5.13
/_SEL1_BUF: CN1.12, JP102.1 (A), SJ3.2, U5.12
/_SIDE: A1.8 (D5), R15.2, SJ11.1, U1.4 (PB15), U6.9
/_SIDE_BUF: CN1.32, SJ11.2, U6.8
/_STEP: A1.5 (D2), R17.2, SJ12.1, U1.2 (PB13), U6.5
/_STEP_BUF: CN1.20, SJ12.2, U6.6
/_TRK0: A1.11 (D8), CN1.26, R2.2, U1.15 (PB7)
/_WRPROT: CN1.28, JP9.2 (B), R1.2, U1.16 (PB8)
GND: A1.4 (GND), A1.29 (GND), C1.2, C2.2, C3.2, C6.2, C7.2, C8.2, C9.2, CN1.1, CN1.3, CN1.5, CN1.7, CN1.9, CN1.11, CN1.13, CN1.15, CN1.17, CN1.19, CN1.21, CN1.23, CN1.25, CN1.27, CN1.29, CN1.31, D1.1 (K), D3.1 (K), D4.1 (K), H1.1, H2.1, H3.1, H4.1, H5.1, J1.4, J2.2, J2.3, J3.3, J4.4 (GND), J4.5 (Shield), J5.5, J5.6, J6.3, J6.5, J7.6, J8.4, J9.6, JP2.3 (B), JP3.3 (B), JP4.3 (B), JP5.2 (B), JP9.1 (A), JP11.1 (A), P1.2, P1.3, Q1.1 (G), R6.2, R12.1, REG1.3, SW1.2, U1.19 (GND), U1.39 (GND), U1.40 (GND), U1.44 (GND), U1.47 (GND), U1.50 (GND), U2.2 (GND), U3.2 (GND), U4.3 (GND), U5.7 (GND), U6.7 (GND); also elsewhere on the board
unnamed: CN1.24, JP10.2 (B)
unnamed: CN1.33, R13.1
unnamed: CN1.34, JP101.1 (A)
unnamed 80: D1.2 (A), R8.1; also elsewhere on the board
unnamed 81: D2.2 (A), R9.1; also elsewhere on the board
unnamed 82: D3.2 (A), R10.1; also elsewhere on the board

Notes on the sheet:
Floppy Data
[Optional] R7 replaces R10 on the Blue Pill. You MUST remove R10 on the Blue Pill when installing R7.
12V to 5V Regulation
5V to 3.3V Regulation
Voltage Jumpers
USB B Port
Floppy Data and Power
Arduino Nano
Blue Pill
Status LEDs and Reset
Reverse Polarity Protection
27k for 5V 44.2k for 3V3
Mounting Holes
Rotate 180
Rotate 0
128x64
SSD1306
SH1106
128x32
Feeback
C3 cap should be rated 16V or higher!
F1 Plus
GW F1 ID
DON'T MOVE!
ESD Protection
Output Pullups
Output Buffers
Input Pullups
Flippy
## A6/A7 Cannot be used as input by digitalRead() ##
USER PIN 2
USER PIN 4
USER PIN 6
USER PIN 4
USER PIN 6
PIN 10
PIN 12
Join Amiga/Shugart S0 (Pin 10) with PC/IBM DRVSB (Pin 12) Required to allow Amiga drives to be used in WinUAE.
PIN 34
PIN 2

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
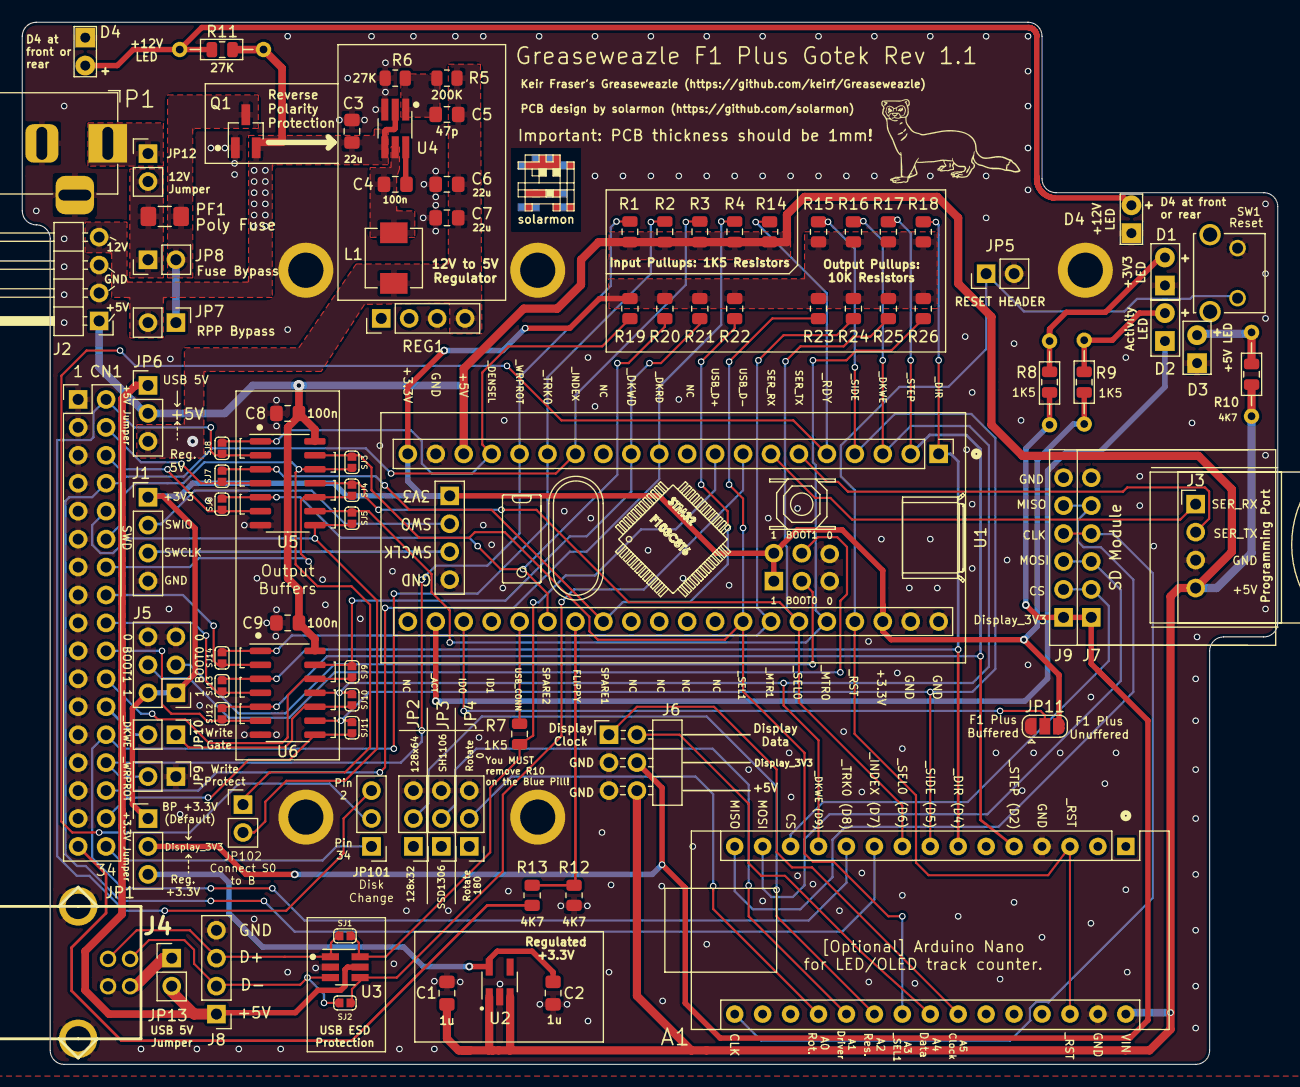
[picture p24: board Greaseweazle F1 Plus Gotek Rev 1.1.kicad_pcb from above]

Board: 2 copper layers, 114.1 x 94.7 mm, 104 parts (1 on the bottom side), 75 nets.

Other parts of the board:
D4#2: +12V LED; LED_D3.0mm_Horizontal_O3.81mm_Z6.0mm
G**: Weasle; WeasleLogo
R8#2, R9#2: 1K5; R_0805_2012Metric
R10#2: 4K7; R_0805_2012Metric
R11#2: 27K; R_0805_2012Metric
solarmon: solarmon-logo-25mils
solarmon#2: solarmon-logo-25mils

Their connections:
+3V3: R9#2.2; also elsewhere on the board
+5V: R10#2.2; also elsewhere on the board
/Display_3V3: R8#2.2; also elsewhere on the board
GND: D4#2.1; also elsewhere on the board
unnamed 80: R8#2.1; also elsewhere on the board
unnamed 81: R9#2.1; also elsewhere on the board
unnamed 82: R10#2.1; also elsewhere on the board

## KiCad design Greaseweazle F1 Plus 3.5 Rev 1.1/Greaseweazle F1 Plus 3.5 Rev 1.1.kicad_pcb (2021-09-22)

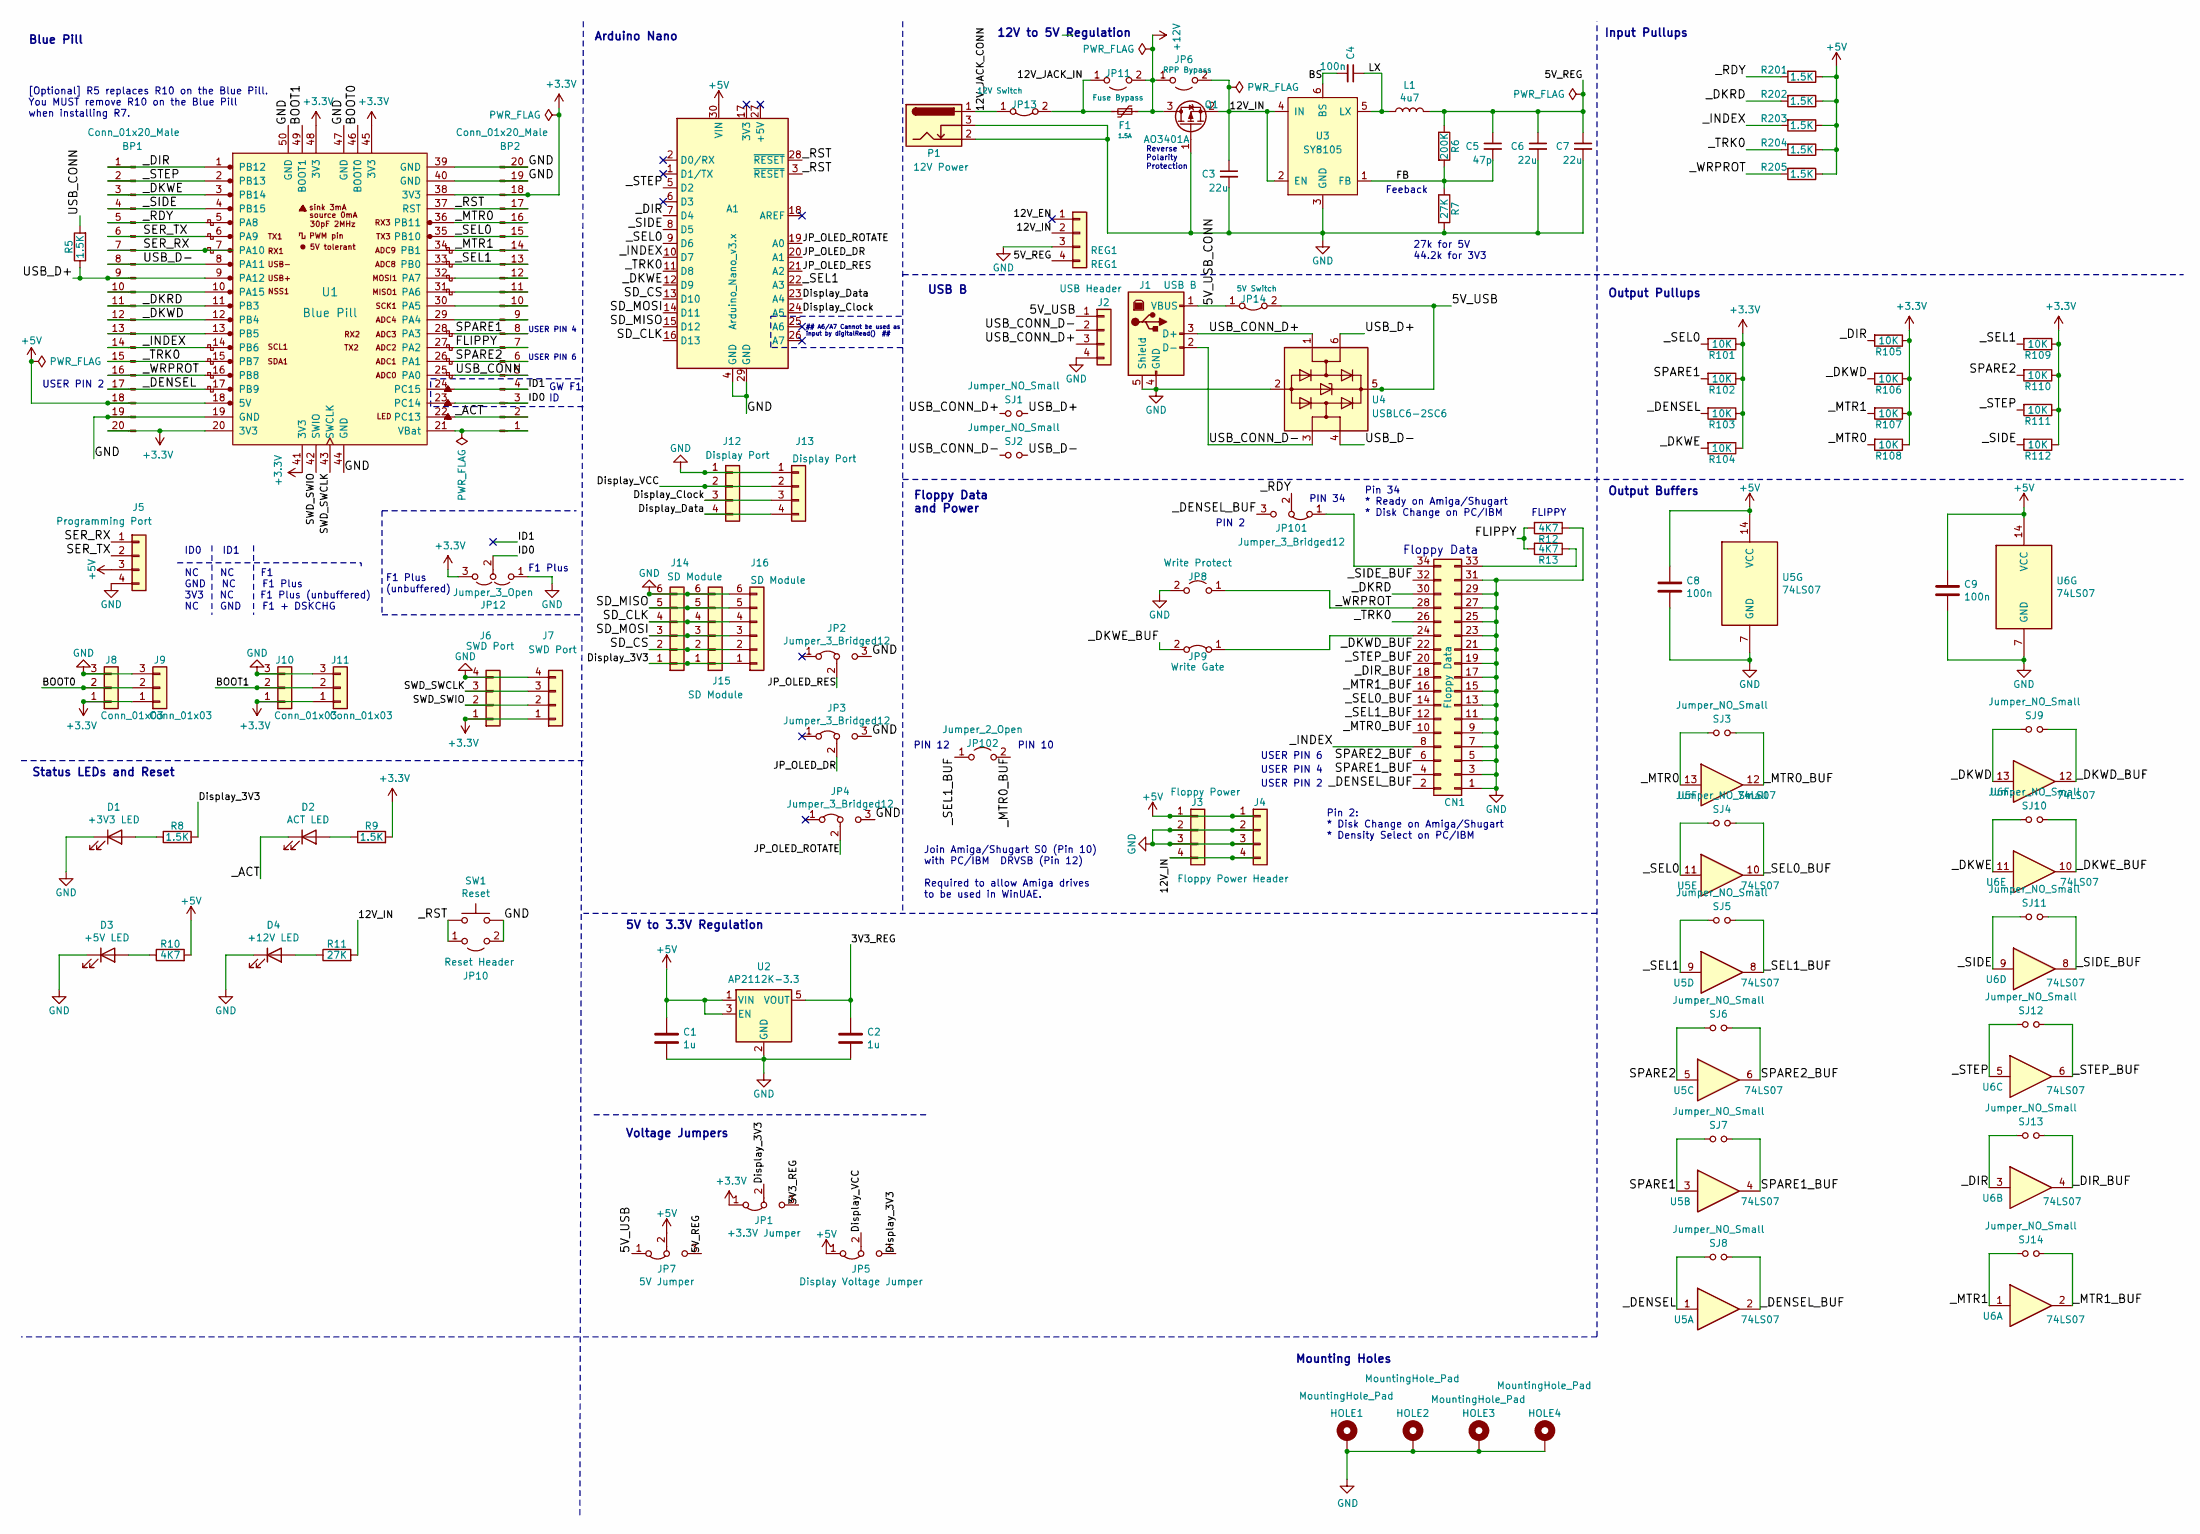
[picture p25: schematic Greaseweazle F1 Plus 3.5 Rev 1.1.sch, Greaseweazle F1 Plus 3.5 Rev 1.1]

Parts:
A1: Arduino_Nano_v3.x; Arduino_Nano
BP1, BP2: Conn_01x20_Male; PinHeader_1x20_P2.54mm_Vertical
C1, C2: 1u; C_0805_2012Metric_Pad1.15x1.40mm_HandSolder
C3, C6, C7: 22u; C_0805_2012Metric_Pad1.15x1.40mm_HandSolder
C4, C8, C9: 100n; C_0805_2012Metric_Pad1.15x1.40mm_HandSolder
C5: 47p; C_0805_2012Metric_Pad1.15x1.40mm_HandSolder
CN1: Floppy Data; PinHeader_2x17_P2.54mm_Vertical
D1: +3V3 LED; LED_0805_2012Metric_Pad1.15x1.40mm_HandSolder
D2: ACT LED; LED_0805_2012Metric_Pad1.15x1.40mm_HandSolder
D3: +5V LED; LED_0805_2012Metric_Pad1.15x1.40mm_HandSolder
D4: +12V LED; LED_0805_2012Metric_Pad1.15x1.40mm_HandSolder
F1: 1.5A; Fuse_1206_3216Metric_Pad1.42x1.75mm_HandSolder; LCSC C371166
HOLE1, HOLE2, HOLE3, HOLE4: MountingHole_Pad; HOLE_3MM
J1: USB B; conn_usb_B; LCSC C498173
J2: USB Header; PinHeader_1x04_P2.54mm_Vertical
J3: Floppy Power; PinHeader_1x04_P2.54mm_Horizontal
J4: Floppy Power Header; PinHeader_1x04_P2.54mm_Vertical
J5: Programming Port; PinHeader_1x04_P2.54mm_Horizontal
J6, J7: SWD Port; PinHeader_1x04_P2.54mm_Horizontal
J8, J9, J10, J11: Conn_01x03; PinHeader_1x03_P2.54mm_Horizontal
J12, J13: Display Port; PinHeader_1x04_P2.54mm_Vertical
J14, J15, J16: SD Module; SD_Micro_Module_Upside_Down
JP1: +3.3V Jumper; PinHeader_1x03_P2.54mm_Vertical
JP2, JP3, JP4: Jumper_3_Bridged12; PinHeader_1x03_P2.54mm_Vertical
JP5: Display Voltage Jumper; PinHeader_1x03_P2.54mm_Vertical
JP6: RPP Bypass; PinHeader_1x02_P2.54mm_Vertical
JP7: 5V Jumper; PinHeader_1x03_P2.54mm_Vertical
JP8: Write Protect; PinHeader_1x02_P2.54mm_Horizontal
JP9: Write Gate; PinHeader_1x02_P2.54mm_Horizontal
JP10: Reset Header; PinHeader_1x02_P2.54mm_Vertical
JP11: Fuse Bypass; PinHeader_1x02_P2.54mm_Vertical
JP12: Jumper_3_Open; SolderJumper-3_P1.3mm_Open_RoundedPad1.0x1.5mm
JP13: 12V Switch; PinHeader_1x02_P2.54mm_Vertical
JP14: 5V Switch; PinHeader_1x02_P2.54mm_Vertical
JP101: Jumper_3_Bridged12; PinHeader_1x03_P2.54mm_Horizontal
JP102: Jumper_2_Open; PinHeader_1x02_P2.54mm_Vertical
L1: 4u7; MWSA0503S
P1: 12V Power; BarrelJack_Horizontal; LCSC C16214
Q1: AO3401A; SOT-23_Handsoldering; LCSC C15127
R5, R8, R9, R201, R202, R203, R204, R205: 1.5K; R_0805_2012Metric_Pad1.15x1.40mm_HandSolder
R6: 200K; R_0805_2012Metric_Pad1.15x1.40mm_HandSolder
R7, R11: 27K; R_0805_2012Metric_Pad1.15x1.40mm_HandSolder
R10, R12, R13: 4K7; R_0805_2012Metric_Pad1.15x1.40mm_HandSolder
R101, R102, R103, R104, R105, R106, R107, R108, R109, R110, R111, R112: 10K; R_0805_2012Metric_Pad1.15x1.40mm_HandSolder
REG1: REG1; PinHeader_1x04_P2.54mm_Vertical
SJ1, SJ2, SJ3, SJ4, SJ5, SJ6, SJ7, SJ8, SJ9, SJ10, SJ11, SJ12, SJ13, SJ14: Jumper_NO_Small; SolderJumper-2_Open_RoundedPad0.5x1.0mm
SW1: Reset; PUSH_BUTTON_RIGHT_ANGLE
U1: Blue Pill; YAAJ_BluePill_SWD_1_BootPins
U2: AP2112K-3.3; SOT-23-5_HandSoldering; LCSC C51118
U3: SY8105; TSOT-23-6_HandSoldering; LCSC C178247
U4: USBLC6-2SC6; SOT-23-6_Handsoldering; LCSC C7519
U5, U6: 74LS07; SOIC-14_3.9x8.7mm_P1.27mm; LCSC C513513

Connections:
+3V3: BP1.20, BP2.18, J6.1, J7.1, J8.1, J9.1, J10.1, J11.1, JP1.1 (A), JP12.3 (B), R9.2, R101.1, R102.1, R103.1, R104.1, R105.1, R106.1, R107.1, R108.1, R109.1, R110.1, R111.1, R112.1, U1.20 (3V3), U1.38 (3V3), U1.41 (3V3), U1.45 (3V3), U1.48 (3V3); also elsewhere on the board
+5V: A1.30 (VIN), BP1.18, C1.1, C8.1, C9.1, J3.1, J4.1, J5.3, JP5.1 (A), JP7.2 (C), R10.2, R201.1, R202.1, R203.1, R204.1, R205.1, U1.18 (5V), U2.1 (VIN), U2.3 (EN), U5.14 (VCC), U6.14 (VCC); also elsewhere on the board
+12V: F1.1, JP6.1 (A), JP11.2 (B), Q1.3 (D)
/3V3_REG: C2.1, JP1.3 (B), U2.5 (VOUT)
/5V_REG: C5.1, C6.1, C7.1, JP7.3 (B), L1.2, R6.1, REG1.4
/5V_USB: J2.1, JP7.1 (A), JP14.2 (B), U4.5 (VBUS)
/5V_USB_CONN: J1.1 (VBUS), JP14.1 (A)
/12V_EN: REG1.1
/12V_IN: C3.1, J3.4, J4.4, JP6.2 (B), Q1.2 (S), R11.2, REG1.2, U3.2 (EN), U3.4 (IN); also elsewhere on the board
/12V_JACK_CONN: JP13.1 (A), P1.1
/12V_JACK_IN: F1.2, JP11.1 (A), JP13.2 (B)
/BOOT0: J8.2, J9.2, U1.46 (BOOT0)
/BOOT1: J10.2, J11.2, U1.49 (BOOT1)
/BS: C4.2, U3.6 (BS)
/Display_3V3: J14.1, J15.1, J16.1, JP1.2 (C), JP5.3 (B), R8.2; also elsewhere on the board
/Display_Clock: A1.24 (A5), J12.3, J13.3
/Display_Data: A1.23 (A4), J12.4, J13.4
/Display_VCC: J12.2, J13.2, JP5.2 (C)
/FB: C5.2, R6.2, R7.1, U3.1 (FB)
/FLIPPY: BP2.7, R12.2, R13.2, U1.27 (PA2)
/ID0: BP2.3, JP12.2 (C), U1.23 (PC14)
/ID1: BP2.4, U1.24 (PC15)
/JP_OLED_DR: A1.20 (A1), JP3.2 (C)
/JP_OLED_RES: A1.21 (A2), JP2.2 (C)
/JP_OLED_ROTATE: A1.19 (A0), JP4.2 (C)
/LX: C4.1, L1.1, U3.5 (LX)
/SD_CLK: A1.16 (D13), J14.4, J15.4, J16.4
/SD_CS: A1.13 (D10), J14.2, J15.2, J16.2
/SD_MISO: A1.15 (D12), J14.5, J15.5, J16.5
/SD_MOSI: A1.14 (D11), J14.3, J15.3, J16.3
/SER_RX: BP1.7, J5.1, U1.7 (PA10)
/SER_TX: BP1.6, J5.2, U1.6 (PA9)
/SPARE1: BP2.8, R102.2, SJ7.2, U1.28 (PA3), U5.3
/SPARE1_BUF: CN1.4, SJ7.1, U5.4
/SPARE2: BP2.6, R110.2, SJ6.2, U1.26 (PA1), U5.5
/SPARE2_BUF: CN1.6, SJ6.1, U5.6
/SWD_SWCLK: J6.3, J7.3, U1.43 (SWCLK)
/SWD_SWIO: J6.2, J7.2, U1.42 (SWIO)
/USB_CONN: BP2.5, R5.2, U1.25 (PA0); also elsewhere on the board
/USB_CONN_D+: J1.3 (D+), J2.3, SJ1.2, U4.1 (I/O1)
/USB_CONN_D-: J1.2 (D-), J2.2, SJ2.2, U4.3 (I/O2)
/USB_D+: BP1.9, R5.1, SJ1.1, U1.9 (PA12), U4.6 (I/O1); also elsewhere on the board
/USB_D-: BP1.8, SJ2.1, U1.8 (PA11), U4.4 (I/O2)
/_ACT: BP2.2, D2.1 (K), U1.22 (PC13); also elsewhere on the board
/_DENSEL: BP1.17, R103.2, SJ8.2, U1.17 (PB9), U5.1
/_DENSEL_BUF: CN1.2, JP101.3 (B), SJ8.1, U5.2
/_DIR: A1.7 (D4), BP1.1, R105.2, SJ13.2, U1.1 (PB12), U6.3
/_DIR_BUF: CN1.18, SJ13.1, U6.4
/_DKRD: BP1.11, CN1.30, R202.2, U1.11 (PB3)
/_DKWD: BP1.12, R106.2, SJ9.2, U1.12 (PB4), U6.13
/_DKWD_BUF: CN1.22, SJ9.1, U6.12
/_DKWE: A1.12 (D9), BP1.3, R104.2, SJ10.2, U1.3 (PB14), U6.11
/_DKWE_BUF: JP9.2 (B), SJ10.1, U6.10
/_INDEX: A1.10 (D7), BP1.14, CN1.8, R203.2, U1.14 (PB6)
/_MTR0: BP2.16, R108.2, SJ3.2, U1.36 (PB11), U5.13
/_MTR0_BUF: CN1.10, JP102.2 (B), SJ3.1, U5.12
/_MTR1: BP2.14, R107.2, SJ14.2, U1.34 (PB1), U6.1
/_MTR1_BUF: CN1.16, SJ14.1, U6.2
/_RDY: BP1.5, JP101.2 (C), R201.2, U1.5 (PA8)
/_RST: A1.3 (~RESET), A1.28 (~RESET), BP2.17, JP10.1 (A), SW1.1, U1.37 (RST)
/_SEL0: A1.9 (D6), BP2.15, R101.2, SJ4.2, U1.35 (PB10), U5.11
/_SEL0_BUF: CN1.14, SJ4.1, U5.10
/_SEL1: A1.22 (A3), BP2.13, R109.2, SJ5.2, U1.33 (PB0), U5.9
/_SEL1_BUF: CN1.12, JP102.1 (A), SJ5.1, U5.8
/_SIDE: A1.8 (D5), BP1.4, R112.2, SJ11.2, U1.4 (PB15), U6.9
/_SIDE_BUF: CN1.32, SJ11.1, U6.8
/_STEP: A1.5 (D2), BP1.2, R111.2, SJ12.2, U1.2 (PB13), U6.5
/_STEP_BUF: CN1.20, SJ12.1, U6.6
/_TRK0: A1.11 (D8), BP1.15, CN1.26, R204.2, U1.15 (PB7)
/_WRPROT: BP1.16, CN1.28, JP8.1 (A), R205.2, U1.16 (PB8)
GND: A1.4 (GND), A1.29 (GND), BP1.19, BP2.19, BP2.20, C1.2, C2.2, C3.2, C6.2, C7.2, C8.2, C9.2, CN1.1, CN1.3, CN1.5, CN1.7, CN1.9, CN1.11, CN1.13, CN1.15, CN1.17, CN1.19, CN1.21, CN1.23, CN1.25, CN1.27, CN1.29, CN1.31, D1.1 (K), D3.1 (K), D4.1 (K), HOLE1.1, HOLE2.1, HOLE3.1, HOLE4.1, J1.4 (GND), J1.5 (Shield), J2.4, J3.2, J3.3, J4.2, J4.3, J5.4, J6.4, J7.4, J8.3, J9.3, J10.3, J11.3, J12.1, J13.1, J14.6, J15.6, J16.6, JP2.3 (B), JP3.3 (B), JP4.3 (B), JP8.2 (B), JP10.2 (B), JP12.1 (A), P1.2, P1.3, Q1.1 (G), R7.2, R12.1, REG1.3, SW1.2, U1.19 (GND), U1.39 (GND), U1.40 (GND), U1.44 (GND), U1.47 (GND), U1.50 (GND), U2.2 (GND), U3.3 (GND), U4.2 (GND), U5.7 (GND), U6.7 (GND); also elsewhere on the board
unnamed: BP1.10, U1.10 (PA15)
unnamed: BP1.13, U1.13 (PB5)
unnamed: BP2.1, U1.21 (VBat)
unnamed: BP2.9, U1.29 (PA4)
unnamed: BP2.10, U1.30 (PA5)
unnamed: BP2.11, U1.31 (PA6)
unnamed: BP2.12, U1.32 (PA7)
unnamed: CN1.24, JP9.1 (A)
unnamed: CN1.33, R13.1
unnamed: CN1.34, JP101.1 (A)
unnamed 89: D1.2 (A), R8.1; also elsewhere on the board
unnamed 90: D2.2 (A), R9.1; also elsewhere on the board
unnamed 91: D3.2 (A), R10.1; also elsewhere on the board
unnamed 92: D4.2 (A), R11.1; also elsewhere on the board

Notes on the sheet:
Floppy Data
[Optional] R5 replaces R10 on the Blue Pill. You MUST remove R10 on the Blue Pill when installing R7.
Feeback
27k for 5V 44.2k for 3V3
Reverse Polarity Protection
12V to 5V Regulation
5V to 3.3V Regulation
Floppy Data and Power
Blue Pill
Arduino Nano
Voltage Jumpers
USB B
Mounting Holes
Status LEDs and Reset
GW F1 ID
F1 Plus
FLIPPY
Input Pullups
Output Pullups
Output Buffers
USER PIN 2
USER PIN 4
USER PIN 6
## A6/A7 Cannot be used as input by digitalRead() ##
Join Amiga/Shugart S0 (Pin 10) with PC/IBM DRVSB (Pin 12) Required to allow Amiga drives to be used in WinUAE.
PIN 12
PIN 10
PIN 34
PIN 2
Pin 34 * Ready on Amiga/Shugart * Disk Change on PC/IBM
Pin 2: * Disk Change on Amiga/Shugart * Density Select on PC/IBM
F1 Plus (unbuffered)
ID0 ID1 NC NC F1 GND NC F1 Plus 3V3 NC F1 Plus (unbuffered) NC GND F1 + DSKCHG

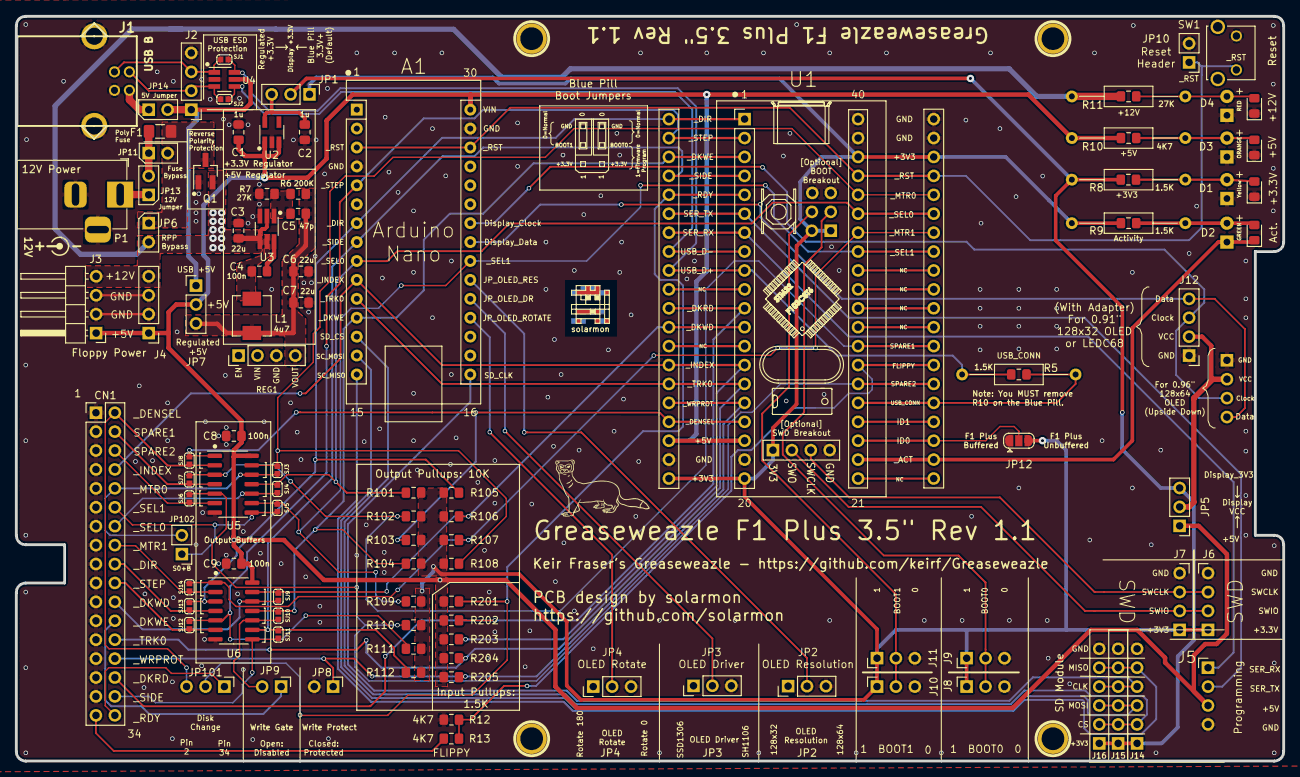
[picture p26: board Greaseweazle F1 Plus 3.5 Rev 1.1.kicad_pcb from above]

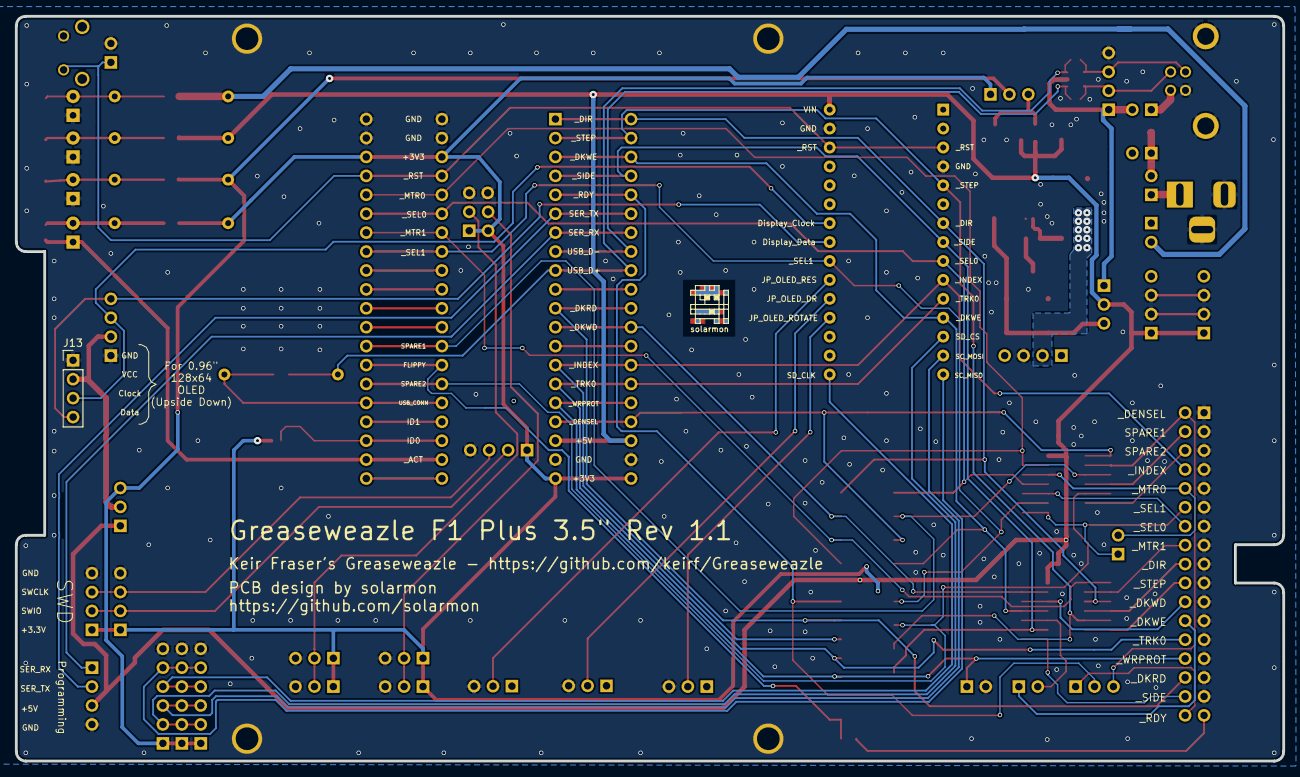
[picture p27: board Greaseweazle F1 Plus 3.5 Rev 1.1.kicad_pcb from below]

Board: 2 copper layers, 170.2 x 100.0 mm, 122 parts (2 on the bottom side), 84 nets.

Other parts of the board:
D1#2, D2#2, D3#2: LED_D3.0mm_Horizontal_O1.27mm_Z6.0mm
D4#2: +12V LED; LED_0805_2012Metric_Pad1.15x1.40mm_HandSolder
Floppy Drive: Floppy_Drive
G**: Weasle; WeasleLogo
HEX: Hex_standoff_m3_15mm
HEX#2, HEX#3, HEX#4: Hex_standoff_m3_15mm
R5#2, R8#2, R9#2, R10#2: R_Axial_DIN0207_L6.3mm_D2.5mm_P15.24mm_Horizontal
R11#2: 27K; R_0805_2012Metric_Pad1.15x1.40mm_HandSolder
solarmon: solarmon-logo-25mils
solarmon#2: solarmon-logo-25mils

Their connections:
+3V3: R9#2.2; also elsewhere on the board
+5V: R10#2.2; also elsewhere on the board
/12V_IN: R11#2.2; also elsewhere on the board
/Display_3V3: R8#2.2; also elsewhere on the board
/USB_CONN: R5#2.2; also elsewhere on the board
/USB_D+: R5#2.1; also elsewhere on the board
/_ACT: D2#2.1; also elsewhere on the board
GND: D1#2.1, D3#2.1, D4#2.1; also elsewhere on the board
unnamed 89: D1#2.2, R8#2.1; also elsewhere on the board
unnamed 90: D2#2.2, R9#2.1; also elsewhere on the board
unnamed 91: D3#2.2, R10#2.1; also elsewhere on the board
unnamed 92: D4#2.2, R11#2.1; also elsewhere on the board

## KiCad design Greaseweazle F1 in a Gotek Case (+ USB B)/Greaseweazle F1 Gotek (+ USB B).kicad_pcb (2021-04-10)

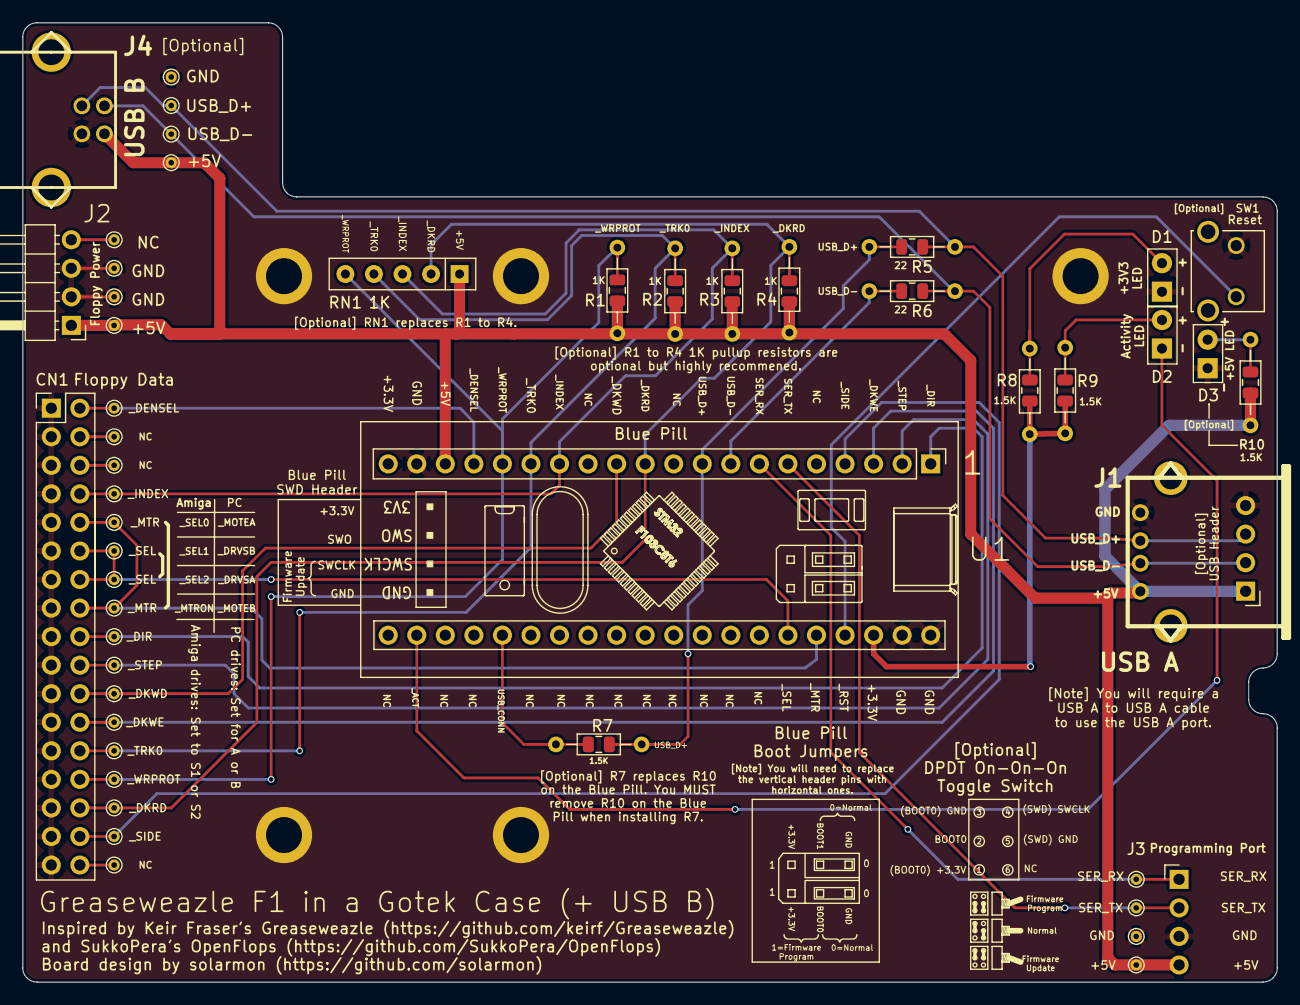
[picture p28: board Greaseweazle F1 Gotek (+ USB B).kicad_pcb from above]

Board: 2 copper layers, 111.6 x 85.3 mm, 37 parts (0 on the bottom side), 27 nets.

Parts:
CN1: Floppy Data; PinHeader_2x17_P2.54mm_Vertical
D1: +3V3 LED; LED_D3.0mm_Horizontal_O6.35mm_Z10.0mm
D2: ACT LED; LED_D3.0mm_Horizontal_O6.35mm_Z10.0mm
D3: +5V Pwr; LED_D3.0mm_Horizontal_O3.81mm_Z6.0mm
H1, H2, H3, H4, H5: MountingHole_Pad; MountingHole_M3_Pad
J1: USB A; conn_usb_A
J1#2: PinHeader_1x04_P2.54mm_Vertical; PinHeader_1x04_P2.54mm_Horizontal
J2: Floppy Power; PinHeader_1x04_P2.54mm_Horizontal
J3: Programming Port; PinHeader_1x04_P2.54mm_Horizontal
J4: USB B; conn_usb_B
R1, R2, R3, R4, R5, R6, R7, R8, R9, R10: R_Axial_DIN0204_L3.6mm_D1.6mm_P7.62mm_Horizontal
R1#2, R2#2, R3#2, R4#2: 1K; R_0805_2012Metric
R5#2, R6#2: 22; R_0805_2012Metric
R7#2, R8#2, R9#2, R10#2: 1.5K; R_0805_2012Metric
RN1: 1K; R_Array_SIP5
SW1: Reset; PUSH_BUTTON_RIGHT_ANGLE
U1: Blue Pill; YAAJ_BluePill_1

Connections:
+3V3: R8.2, R8#2.2, R9.2, R9#2.2, U1.38
+5V: J1.1, J1#2.1, J2.1, J3.4, J4.1, R1.1, R1#2.1, R2.1, R2#2.1, R3.1, R3#2.1, R4.1, R4#2.1, R10.2, R10#2.2, RN1.1, U1.18
/SER_RX: J3.1, U1.7
/SER_TX: J3.2, U1.6
/USB_CONN: R7.2, R7#2.2, U1.25
/USB_D+: R5.2, R5#2.2, R7.1, R7#2.1, U1.9
/USB_D-: R6.2, R6#2.2, U1.8
/_ACT: D2.1, U1.22
/_DENSEL: CN1.2, U1.17
/_DIR: CN1.18, U1.1
/_DKRD: CN1.30, R4.2, R4#2.2, RN1.2, U1.11
/_DKWD: CN1.22, U1.12
/_DKWE: CN1.24, U1.3
/_INDEX: CN1.8, R3.2, R3#2.2, RN1.3, U1.14
/_MTR: CN1.10, CN1.16, U1.36
/_RST: SW1.1, U1.37
/_SEL: CN1.12, CN1.14, U1.35
/_SIDE: CN1.32, U1.4
/_STEP: CN1.20, U1.2
/_TRK0: CN1.26, R2.2, R2#2.2, RN1.4, U1.15
/_WRPROT: CN1.28, R1.2, R1#2.2, RN1.5, U1.16
GND: CN1.1, CN1.3, CN1.5, CN1.7, CN1.9, CN1.11, CN1.13, CN1.15, CN1.17, CN1.19, CN1.21, CN1.23, CN1.25, CN1.27, CN1.29, CN1.31, CN1.33, D1.1, D3.1, H1.1, H2.1, H3.1, H4.1, H5.1, J1.4, J1#2.4, J2.2, J2.3, J3.3, J4.4, SW1.2, U1.19, U1.39, U1.40
unnamed: D1.2, R8.1, R8#2.1
unnamed: D2.2, R9.1, R9#2.1
unnamed: D3.2, R10.1, R10#2.1
unnamed: J1.2, J1#2.2, J4.2, R6.1, R6#2.1
unnamed: J1.3, J1#2.3, J4.3, R5.1, R5#2.1

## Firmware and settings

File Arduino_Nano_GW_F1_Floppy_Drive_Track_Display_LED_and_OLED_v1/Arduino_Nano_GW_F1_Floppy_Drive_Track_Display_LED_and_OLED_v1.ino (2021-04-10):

/***************************************************************************/
// GW F1 (Gotek and 3.5 custom boards) Floppy Drive Tracker - LEDC68 and OLED
// Supports following screens:
// * LEDC68
// * 0.91" 128x32 I2C OLED
// * 0.96" 128x64 I2C OLED
//
// Following OLED driver libraries supported
// * SSD1306
// * SSH1106 (TBC)
/**************************************************************************/

const char *myDescription = "Greaseweazle F1 (Gotek or 3.5) Track Display";

const char *myVersion = "v1.0";

#include <Adafruit_GFX.h>
#include <Adafruit_SSD1306.h>

#include "I2CScanner.h"

// Setup I2C scanner
I2CScanner scanner;
byte i2c_address;
int i2c_found_count = 0;
byte i2c_found_address;

enum ScreenType {
  NONE,
  LED,
  LCD,
  OLED
};

ScreenType screen_type = NONE;

// Include libraries for OLED screen - assumed to be SSD1306

#include <Adafruit_SSD1306.h>
#include <Adafruit_GFX.h>


#include "TM1651.h"

//Define LED screen pins
int DIO_Pin = 18;    // A4
int CLK_Pin = 19;    // A5

// Define drive signal pins
const byte STEP_Pin = 2;   // D2 (D2 and D3 are interrupt capable)

int DIR_Pin = 4;    // D4
int SIDE_Pin = 5;   // D5
int SEL_Pin = 6;   // D6
int INDEX_Pin = 7;  // D7
int TRK0_Pin = 8;   // D8
int DKWE_Pin = 9;   // D9

int JP_SPARE_Pin = 14;      // D14 / A0
int JP_OLED_DR_Pin = 15;    // D15 / A1
int JP_OLED_RES_Pin = 16;   // D16 / A2


// variables to store the drive signal states
int DIR_State = 0;
int STEP_State = 0;
int SIDE_State = 0;
int SIDE_Last = 0;  // For edge detection - for activity counter
int INDEX_State = 0;
int TRK0_State = 0;
int SEL_State = 0;
int DKWE_State = 0;

int JP_OLED_RES_State = 0;
int JP_OLED_DR_State = 0;
int JP_SPARE_State = 0;

// Track position
int TRACK_POS = 0;
int TRACK_TENS = 0;
int TRACK_UNITS = 0;

// Note: D13 is used by onboard LED
const byte ledPin = 13;
int counter = 0;


// OLED
#define OLED_RESET 4

int oled_w = 128; // default oled width
int oled_h = 32;  // defaylt oled height

// Default font sizes
int font_1_w = 6;
int font_1_h = 8;

int font_2_w = 12;
int font_2_h = 16;

int font_3_w = 18;
int font_3_h = 24;

int font_4_w = 24;
int font_4_h = 32;

// ----------------------------------------------------------

// 'Greaseweazle - logo', 128x48px
const unsigned char myBitmap [] PROGMEM = {
  0x00, 0x00, 0x00, 0x00, 0x00, 0x00, 0x00, 0x00, 0x00, 0x00, 0x00, 0x00, 0x00, 0x00, 0x00, 0x00, 
  0x00, 0x00, 0x00, 0x00, 0x00, 0x00, 0x00, 0x00, 0x00, 0x00, 0x00, 0x00, 0x00, 0x00, 0x00, 0x00, 
  0x00, 0x00, 0x00, 0x00, 0x00, 0x00, 0x00, 0x00, 0x00, 0x00, 0x00, 0x00, 0x00, 0x00, 0x00, 0x00, 
  0x00, 0x00, 0x00, 0x00, 0x00, 0x00, 0x00, 0x00, 0x00, 0x00, 0x7c, 0x00, 0x00, 0x00, 0x00, 0x00, 
  0x00, 0x00, 0x00, 0x00, 0x00, 0x00, 0x00, 0x00, 0x00, 0x0f, 0x8e, 0x00, 0x00, 0x00, 0x00, 0x00, 
  0x00, 0x00, 0x00, 0x00, 0x00, 0x00, 0x00, 0x00, 0x00, 0x0f, 0x0f, 0x00, 0x00, 0x00, 0x00, 0x00, 
  0x00, 0x00, 0x00, 0x00, 0x00, 0xff, 0xff, 0xff, 0xff, 0xf0, 0x13, 0x80, 0x00, 0x00, 0x00, 0x00, 
  0x00, 0x00, 0x00, 0x00, 0x01, 0xfc, 0x00, 0x00, 0x00, 0x00, 0x61, 0x80, 0x00, 0x00, 0x00, 0x00, 
  0x00, 0x00, 0x00, 0x00, 0x01, 0x9c, 0x00, 0x00, 0x00, 0x00, 0x61, 0x80, 0x00, 0x00, 0x00, 0x00, 
  0x00, 0x00, 0x00, 0x00, 0x01, 0x03, 0x80, 0x00, 0x00, 0x00, 0x71, 0x80, 0x00, 0x00, 0x00, 0x00, 
  0x00, 0x00, 0x00, 0x00, 0x01, 0x07, 0x80, 0x00, 0x00, 0x00, 0x31, 0x80, 0x00, 0x00, 0x00, 0x00, 
  0x00, 0x00, 0x00, 0x00, 0x01, 0x0f, 0x80, 0x00, 0x00, 0x00, 0x31, 0x80, 0x00, 0x00, 0x00, 0x00, 
  0x00, 0x00, 0x00, 0x00, 0x01, 0x1c, 0x00, 0x00, 0x00, 0x00, 0x31, 0x80, 0x00, 0x00, 0x00, 0x00, 
  0x00, 0x00, 0x00, 0x00, 0x01, 0x18, 0x00, 0x00, 0x00, 0x00, 0x11, 0x80, 0x00, 0x00, 0x00, 0x00, 
  0x00, 0x00, 0x00, 0x00, 0x01, 0x90, 0x00, 0x00, 0x01, 0xf0, 0x0f, 0x80, 0x00, 0x00, 0x00, 0x00, 
  0x00, 0x00, 0x00, 0x00, 0x01, 0xe0, 0x7f, 0x80, 0x06, 0x0e, 0x0c, 0x00, 0x00, 0x00, 0x00, 0x00, 
  0x00, 0x00, 0x00, 0x00, 0x00, 0xe0, 0x7f, 0xc0, 0x0e, 0x0e, 0x0c, 0x00, 0x00, 0x00, 0x00, 0x00, 
  0x00, 0x00, 0x00, 0x00, 0x00, 0x60, 0x81, 0xe0, 0x70, 0x01, 0x8e, 0x00, 0x00, 0x00, 0x00, 0x00, 
  0x00, 0x00, 0x00, 0x00, 0x00, 0x70, 0x00, 0xe0, 0xf0, 0x01, 0x86, 0x00, 0x00, 0x00, 0x00, 0x00, 
  0x00, 0x00, 0x00, 0x00, 0x00, 0x70, 0x1c, 0x1f, 0xe0, 0x31, 0x82, 0x00, 0x00, 0x00, 0x00, 0x00, 
  0x00, 0x00, 0x00, 0x00, 0x00, 0x62, 0x1c, 0x1c, 0x63, 0xfc, 0x42, 0x00, 0x00, 0x00, 0x00, 0x00, 
  0x00, 0x00, 0x00, 0x00, 0x00, 0x63, 0x1c, 0x18, 0x63, 0xfc, 0x42, 0x00, 0x00, 0x00, 0x00, 0x00, 
  0x00, 0x00, 0x00, 0x00, 0x00, 0xe3, 0x1b, 0x90, 0x63, 0xfc, 0x62, 0x00, 0x00, 0x00, 0x00, 0x00, 
  0x00, 0x00, 0x00, 0x00, 0x00, 0xe3, 0x1f, 0x90, 0x07, 0xe0, 0x62, 0x00, 0x00, 0x00, 0x00, 0x00, 
  0x00, 0x00, 0x00, 0x00, 0x00, 0xe3, 0x1f, 0x90, 0x07, 0xc0, 0x62, 0x00, 0x00, 0x00, 0x00, 0x00, 
  0x00, 0x00, 0x00, 0x00, 0x00, 0xe3, 0x0f, 0x00, 0x00, 0x00, 0x62, 0x00, 0x00, 0x00, 0x00, 0x00, 
  0x00, 0x00, 0x00, 0x00, 0x00, 0xc3, 0x08, 0x00, 0x00, 0x00, 0x82, 0x00, 0x00, 0x00, 0x00, 0x00, 
  0x00, 0x00, 0x00, 0x00, 0x00, 0x83, 0x10, 0x00, 0x00, 0x01, 0x82, 0x00, 0x00, 0x00, 0x00, 0x00, 
  0x00, 0x00, 0x00, 0x00, 0x00, 0x83, 0x03, 0xff, 0xfc, 0x01, 0x82, 0x00, 0x00, 0x00, 0x00, 0x00, 
  0x00, 0x00, 0x00, 0x00, 0x00, 0xc1, 0x04, 0xf0, 0xf4, 0x01, 0x86, 0x00, 0x00, 0x00, 0x00, 0x00, 
  0x00, 0x00, 0x00, 0x00, 0x00, 0xe0, 0x84, 0x60, 0x62, 0x01, 0x8e, 0x00, 0x00, 0x00, 0x00, 0x00, 
  0x00, 0x00, 0x00, 0x00, 0x00, 0x70, 0xe0, 0x10, 0xe1, 0x82, 0x0c, 0x00, 0x00, 0x00, 0x00, 0x00, 
  0x00, 0x00, 0x00, 0x00, 0x00, 0x38, 0xe0, 0x11, 0xc1, 0x82, 0x0c, 0x00, 0x00, 0x00, 0x00, 0x00, 
  0x00, 0x00, 0x00, 0x00, 0x00, 0x18, 0x70, 0x0e, 0x01, 0xf0, 0x1c, 0x00, 0x00, 0x00, 0x00, 0x00, 
  0x00, 0x00, 0x00, 0x00, 0x00, 0x0c, 0x00, 0x06, 0x01, 0xf3, 0xf8, 0x00, 0x00, 0x00, 0x00, 0x00, 
  0x00, 0x00, 0x00, 0x00, 0x00, 0x04, 0x00, 0x03, 0x01, 0xf3, 0xf0, 0x00, 0x00, 0x00, 0x00, 0x00, 
  0x00, 0x00, 0x00, 0x00, 0x00, 0x06, 0x04, 0x7f, 0xe3, 0xfc, 0x60, 0x00, 0x00, 0x00, 0x00, 0x00, 
  0x00, 0x00, 0x00, 0x00, 0x00, 0x07, 0xfe, 0x3f, 0xc7, 0xf8, 0x60, 0x00, 0x00, 0x00, 0x00, 0x00, 
  0x00, 0x00, 0x00, 0x00, 0x00, 0x03, 0xff, 0x00, 0x0c, 0x00, 0x60, 0x00, 0x00, 0x00, 0x00, 0x00, 
  0x00, 0x00, 0x00, 0x00, 0x00, 0x03, 0xc3, 0x80, 0x00, 0x00, 0x60, 0x00, 0x00, 0x00, 0x00, 0x00, 
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
};



// ----------------------------------------------------------

void found_i2c(byte i2c_address)
{
  i2c_found_count = i2c_found_count + 1;
  i2c_found_address = i2c_address;
  
  //Serial.print(F("### found_i2c() - i2c_found_count: "));
  //Serial.print(i2c_found_count);
  //Serial.println(F(" ###"));

  //Serial.print(F("### found_i2c() - i2c_address: 0x"));
  //Serial.print(i2c_address, HEX);
  //Serial.println(F(" ###"));
}

void stepping()
{
  //Serial.println(F("### stepping() - FALLING ###"));

  // Read current DIR state
  DIR_State = digitalRead(DIR_Pin);

  // Increment or decrement Track position
  switch (DIR_State)
  {
    case 0:
      {
        TRACK_POS = TRACK_POS + 1;
        break;
      }

    case 1:
      {
        if (TRACK_POS > 0) // only if it is greater than 0
        {
          TRACK_POS = TRACK_POS - 1;
        }
        break;
      }
  }

  counter++;
}

void(* resetFunc) (void) = 0; //declare reset function @ address 0

void setup()
{
  Serial.begin(9600);
  while (!Serial) {};

  // -----------------------

  Serial.println(F("---------------------------"));
  Serial.println(F("###"));
  
  Serial.print(F("### "));
  Serial.print(myDescription);
  Serial.println(F(" ###"));
  
  Serial.print(F("### "));
  Serial.print(myVersion);
  Serial.println(F(" ###"));
  
  Serial.println(F("###"));

  // Set digital input pins with internal pullups

  pinMode(DIR_Pin, INPUT_PULLUP);

  // Make interrupt for STEP pin, so that falling edge can be detected.
  pinMode(STEP_Pin, INPUT_PULLUP);
  attachInterrupt(digitalPinToInterrupt(STEP_Pin), stepping, FALLING);
  pinMode(INDEX_Pin, INPUT_PULLUP);
  pinMode(SIDE_Pin, INPUT_PULLUP);
  pinMode(TRK0_Pin, INPUT_PULLUP);
  pinMode(SEL_Pin, INPUT_PULLUP);
  pinMode(DKWE_Pin, INPUT_PULLUP);

  //----------------------------

  // Check Jumpers

  pinMode(JP_SPARE_Pin, INPUT_PULLUP);
  pinMode(JP_OLED_RES_Pin, INPUT_PULLUP);
  pinMode(JP_OLED_DR_Pin, INPUT_PULLUP);

  JP_SPARE_State = digitalRead(JP_SPARE_Pin);
  JP_OLED_RES_State = digitalRead(JP_OLED_RES_Pin);
  JP_OLED_DR_State = digitalRead(JP_OLED_DR_Pin);

  Serial.print(F("### JP_SPARE_State: "));
  Serial.print(JP_SPARE_State);
  Serial.println(" ###");

  Serial.print(F("### JP_OLED_RES_State: "));
  Serial.print(JP_OLED_RES_State);
  Serial.println(F(" ###"));

  Serial.print(F("### JP_OLED_DR_State: "));
  Serial.print(JP_OLED_DR_State);
  Serial.println(F(" ###"));

  switch (JP_OLED_RES_State)
  {
    case 1:
      {

        oled_w = 128; // default oled width
        oled_h = 32;  // defaylt oled height
        
        Serial.print(F("### JUMPER: OLED Resolution: "));
        Serial.print(oled_w);
        Serial.print(F("x"));
        Serial.print(oled_h);
        Serial.println (F(" ###"));

        break;
      }
    case 0:
      {

        oled_w = 128; // default oled width
        oled_h = 64;  // defaylt oled height


        Serial.print(F("### JUMPER: OLED Resolution: "));
        Serial.print(oled_w);
        Serial.print(F("x"));
        Serial.print(oled_h);
        Serial.println (F(" ###"));
        break;
      }
  }

  switch (JP_OLED_DR_State)
  {
    case 1:
      {
        Serial.println(F("### JUMPER: OLED Driver: SSD1306 ###"));
        break;
      }
    case 0:
      {
        Serial.println(F("### JUMPER: OLED Driver: SH1106 ###"));
        break;
      }
  }


  //----------------------------

  // Scan for I2C screens

  //Serial.println(F("### Screen Scan: Init... ###"));
  scanner.Init();

  //Serial.println(F("### Screen Scan: Execute... ###"));
  scanner.Execute(found_i2c);

  //Serial.println(F("### Screen Scan: Done... ###"));

  if (i2c_found_count == 0) {
    screen_type = NONE;
    Serial.println(F("### Screen Type: NONE !!! ###"));
  }
  else if (i2c_found_count == 1) {
    screen_type = OLED;
    Serial.println(F("### Screen Type: OLED ###"));
  }
  else if (i2c_found_count > 100) {
    screen_type = LED;
    Serial.println(F("### Screen Type: LED ###"));
  }

  switch (screen_type) {

    case LED:
      {
        Serial.println(F("### LED screen found! ###"));

        // Reset I2C bus
        TWCR = 0;

        // Create TM1651Display
        TM1651 Display(CLK_Pin, DIO_Pin);

        Serial.println(F("### LED: TM1651 display created ###"));

        // Set display brightness
        Display.displaySet(0);//BRIGHT_TYPICAL = 2,BRIGHT_DARKEST = 0,BRIGHTEST = 7;

        Serial.println(F("### LED: Display brightness set to 0 ###"));

        delay(300);

        // Initialise screen
        Display.displayNum(0, 20);
        Display.displayNum(1, 20);
        Display.displayNum(2, 20);

        Serial.println(F("### LED: Display initialised (---) ###"));

        delay(300);

        while (1)
        {
          // Poll the drive signals
          DIR_State = digitalRead(DIR_Pin);
          STEP_State = digitalRead(STEP_Pin);
          SIDE_State = digitalRead(SIDE_Pin);
          INDEX_State = digitalRead(INDEX_Pin);
          TRK0_State = digitalRead(TRK0_Pin);
          SEL_State = digitalRead(SEL_Pin); // LOW = STEP IN; HIGH = STEP OUT
          DKWE_State = digitalRead(DKWE_Pin);

          if (TRK0_State == 0)
          {
            TRACK_POS = 0;

            Display.displayNum(0, 22);  // Show letter 't'
          }

          // DKWE Display
          // This will flash the middle segment briefly - as it is above the SIDE display code.
          if (DKWE_State == 0) //
          {
            Display.displayNum(2, 20);
          }

          // SIDE Display
          if (SIDE_State == 1) // High = Lower head = side 0
          {
            Display.displayNum(2, 21);
            //Display.displayNum(2,17);
          }

          if (SIDE_State == 0) // Low = Upper head = side 1
          {
            Display.displayNum(2, 19);
            //Display.displayNum(2,18);
          }

          if (SIDE_Last != SIDE_State) // edge detection
          {
            counter++;
          }

          SIDE_Last = SIDE_State; // for edge detection

          // Track display
          TRACK_TENS = TRACK_POS / 10;
          TRACK_UNITS = TRACK_POS % 10;

          if (TRACK_TENS == 0)
          {
            if (TRK0_State == 0)
            {
              Display.displayNum(0, 22);  // Show letter 't' (0x78)
            }
            else
            {
              Display.displayNum(0, 16);  // show space/empty character
            }
          }
          else
          {
            Display.displayNum(0, TRACK_TENS);
          }

          Display.displayNum(1, TRACK_UNITS);

          // Change built-in LED state
          if (counter % 2 == 0)
          {
            digitalWrite(ledPin, HIGH);
          }
          else
          {
            digitalWrite(ledPin, LOW);
          }

        } // while loop

        break;
      } // case LED

    case OLED:
      {
        Serial.print(F("### OLED screen found! (0x"));
        Serial.print(i2c_found_address, HEX);
        Serial.println(F(") ###"));

        // Set up OLED:
        Adafruit_SSD1306 oled_display(oled_w, oled_h, &Wire, OLED_RESET);

        //oled_display.begin(SSD1306_SWITCHCAPVCC, i2c_found_address);
        if(!oled_display.begin(SSD1306_SWITCHCAPVCC, i2c_found_address)) { // Address 0x3D for 128x64
          Serial.println(F("SSD1306 allocation failed"));
          for(;;); // Don't proceed, loop forever
        }
        
        oled_display.setRotation(2); // rotate 180 degrees
        oled_display.setTextColor (WHITE); // Only white for an OLED!

        Serial.print(F("### OLED:  Adafruit_SSD1306 screen created (0x"));
        Serial.print(i2c_found_address, HEX);
        Serial.println(F(") ###"));
       
        // For some reason, the DIR pin mode needs to be set again when an OLED screen is used.
        pinMode(DIR_Pin, INPUT_PULLUP);

        // 
        // Loading screen
        oled_display.clearDisplay(); //for Clearing the display
         switch(oled_h)
          {
            case 32:
            {
              oled_display.drawBitmap(0, 0, myBitmap, 128, 32, WHITE); // display.drawBitmap(x position, y position, bitmap data, bitmap width, bitmap height, color)
              oled_display.setCursor (oled_w/2 - (font_1_w*12)/2,oled_h-font_1_h); // position the cursor
              //oled_display.print ("Greaseweazle");
              break;
            }
            case 64:
            {
              oled_display.drawBitmap(0, 0, myBitmap, 128, 48, WHITE); // display.drawBitmap(x position, y position, bitmap data, bitmap width, bitmap height, color)
              oled_display.setTextSize (1); 
              oled_display.setCursor (oled_w/2 - (font_1_w*12)/2,oled_h-font_2_h/2 - font_1_h/2); // position the cursor
              oled_display.print ("Greaseweazle");
              
              break;
            }
          }

          oled_display.display ();
          delay(2000);

        // While loop
        while (1)
        {
          // Poll the drive signals

          DIR_State = digitalRead(DIR_Pin);
          STEP_State = digitalRead(STEP_Pin);
          SIDE_State = digitalRead(SIDE_Pin);
          INDEX_State = digitalRead(INDEX_Pin);
          TRK0_State = digitalRead(TRK0_Pin);
          SEL_State = digitalRead(SEL_Pin); // LOW = STEP IN; HIGH = STEP OUT
          DKWE_State = digitalRead(DKWE_Pin);
          
          oled_display.clearDisplay (); // clear display

          if (TRK0_State == 0)
          {
            TRACK_POS = 0;
          }

          // DKWE text
          if (DKWE_State == 0)
          {
            switch(oled_h)
            {
              case 32:
              {
                oled_display.setTextSize (1); 
                oled_display.setCursor (((oled_w/2) - (font_1_w/2)), 0); // position the cursor
                break;
              }
              case 64:
              {
                oled_display.setTextSize (2); 
                oled_display.setCursor (((oled_w/2) - (font_2_w/2)), oled_h-font_2_h); // position the cursor
                break;
              }
            }
            
            
            //oled_display.setTextColor (WHITE); // white is not default !
            oled_display.print ("*");
          }

          // Track text

          switch(oled_h)
          {
            case 32:
            {
              oled_display.setTextSize (3); 

              if(TRACK_POS < 10) // 1 digit
              {
                oled_display.setCursor (((oled_w/2)-font_3_w-font_2_w),(oled_h/2)-(font_3_h/2));
              }
              else // 2-digits
              {
                oled_display.setCursor (((oled_w/2)-(font_3_w*2)-font_2_w),(oled_h/2)-(font_3_h/2));
              }
              
              break;
            }
            case 64:
            {
              oled_display.setTextSize (4); 

              if(TRACK_POS < 10) // 1 digit
              {
                oled_display.setCursor (((oled_w/2)-(font_4_w))-5, ((oled_h-font_2_h)/2)-(font_4_h/2));
              }
              else // 2-digits
              {
                oled_display.setCursor (((oled_w/2)-(font_4_w*2))-5,((oled_h-font_2_h)/2)-(font_4_h/2));
              }
             
              break;
            }
          }
            
          oled_display.print (TRACK_POS);
          
          // SIDE

          // Dot
          //oled_display.setCursor ((oled_w / 2) - (font_3_w / 2), (oled_h / 2) - (font_3_h / 2));
          //oled_display.print (".");
          switch(oled_h)
          {
            case 32:
            {
              oled_display.fillCircle(oled_w/2,oled_h/2,3,WHITE);
              oled_display.setCursor ((oled_w/2)+12, (oled_h / 2) - (font_3_h / 2));
              break;
            }
            case 64:
            {
              oled_display.fillCircle((oled_w)/2,(oled_h-font_2_h)/2,4,WHITE);
              oled_display.setCursor ((oled_w/2)+10, ((oled_h-font_2_h)/2)-(font_4_h/2));
              break;
            }
          }
          
          // Side value
           oled_display.print (!SIDE_State);

          // Dir text
          oled_display.setTextSize (2); 

          if (DIR_State == 0) // increment
          {
             switch(oled_h)
            {
              case 32:
              {
                oled_display.setCursor ((oled_w/2)+ (font_3_w * 2), (oled_h / 2) - (font_2_h / 2)); // position the cursor
                break;
              }
              case 64:
              {
                oled_display.setCursor (oled_w - font_2_w, (oled_h-font_2_h)); // position the cursor
                break;
              }
            }
            
            oled_display.print (">");
          }

          if (DIR_State == 1) // decrement
          {
               switch(oled_h)
              {
                case 32:
                {
                  if (TRACK_POS < 10) // 1 digit
                  {
                    oled_display.setCursor (((oled_w / 2) - (font_3_w * 3)), (oled_h / 2) - (font_2_h / 2)); // position the cursor
                  }
                  else // 2 digits
                  {
                    oled_display.setCursor (((oled_w / 2) - (font_3_w * 4)), (oled_h / 2) - (font_2_h / 2)); // position the cursor
                  }
                  break;
                }
                case 64:
                {
                  oled_display.setCursor (0,oled_h-font_2_h); // position the cursor
                  break;
                }
              }
            
            

            oled_display.print ("<");
          }

          // Track line
          //
          switch(oled_h)
          {
            case 32:
            {
              oled_display.drawLine(0, oled_h - 1, TRACK_POS, oled_h - 1, WHITE);
              break;
            }
            case 64:
            {
              //oled_display.drawLine(0, oled_h - font_2_h - 1 , TRACK_POS, oled_h - font_2_h - 1, WHITE);
              oled_display.drawLine((oled_w/2) - (TRACK_POS/2), oled_h - font_2_h - 1 , (oled_w/2) + (TRACK_POS/2), oled_h - font_2_h - 1, WHITE);
              break;
            }
          }

          // SEL text

          if (SEL_State == 0)
          {
            switch(oled_h)
            {
              case 32:
              {
                oled_display.setTextSize (1); 
                oled_display.setCursor (oled_w - (font_1_w * 3), 0); // position the cursor
                break;
              }
              case 64:
              {
                oled_display.setTextSize (2); 
                oled_display.setCursor (oled_w*0.75 - ((font_2_w*3)/2), oled_h-font_2_h); // position the cursor
                break;
              }
            }
            
            oled_display.print ("SEL");
          }

          // TRK0 text
          if (TRK0_State == 0)
          {
            switch(oled_h)
            {
              case 32:
              {
                oled_display.setTextSize (1); 
                oled_display.setCursor (0, oled_h-font_1_h); // position the cursor
                break;
              }
              case 64:
              {
                oled_display.setTextSize (2); 
                oled_display.setCursor ((oled_w/4)-(font_2_w/2), oled_h - font_2_h); // position the cursor
                break;
              }
            }

            oled_display.print ("T0");
          }
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
void loop()
{
  //Serial.println("### void LOOP ###");
  //delay(500);
}

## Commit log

2021-04-10 Added KiCAD design files
    [Greaseweazle F1 3.5 Inch Rev 2-B_Cu.gbr, Greaseweazle F1 3.5 Inch Rev 2-B_Mask.gbr, Greaseweazle F1 3.5 Inch Rev 2-B_SilkS.gbr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]
2021-05-02 Added Arduino_Nano_GW_F1_Plus_Floppy_Drive_Track_Display_LED_and_OLED
2021-05-26 Added GW F1 Plus boards - 3.5 and Gotek
    [Greaseweazle F1 Plus 3.5-B_Cu.gbr, Greaseweazle F1 Plus 3.5-B_Mask.gbr, Greaseweazle F1 Plus 3.5-B_SilkS.gbr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]
2021-05-26 Added images and links about the Gw F1 Plus boards
2021-06-05 Some silk screen updates
    [Greaseweazle F1 Plus 3.5-B_Cu.gbr, Greaseweazle F1 Plus 3.5-B_Mask.gbr, Greaseweazle F1 Plus 3.5-B_SilkS.gbr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]
2021-07-10 Added F1 Plus and F1 Plus Mini
    [Greaseweazle F1 Plus Mini-B_Cu.gbr, Greaseweazle F1 Plus Mini-B_Mask.gbr, Greaseweazle F1 Plus Mini-B_SilkS.gbr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]
2021-09-22 Added Rev 1.1 versions
    [Greaseweazle F1 Plus 3.5 Rev 1.1-B_Cu.gbr, Greaseweazle F1 Plus 3.5 Rev 1.1-B_Mask.gbr, Greaseweazle F1 Plus 3.5 Rev 1.1-B_SilkS.gbr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]
2021-09-22 Updated to Rev 1.1 boards
